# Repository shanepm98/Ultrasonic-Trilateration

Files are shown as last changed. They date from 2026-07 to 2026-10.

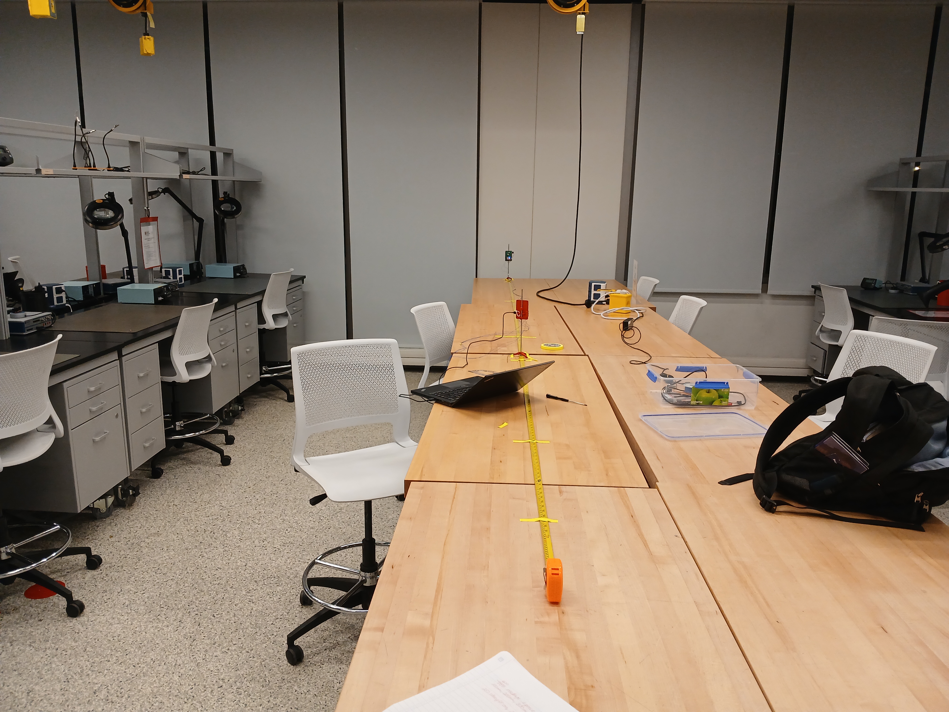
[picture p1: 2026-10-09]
pics/Testing/test_setup.jpg

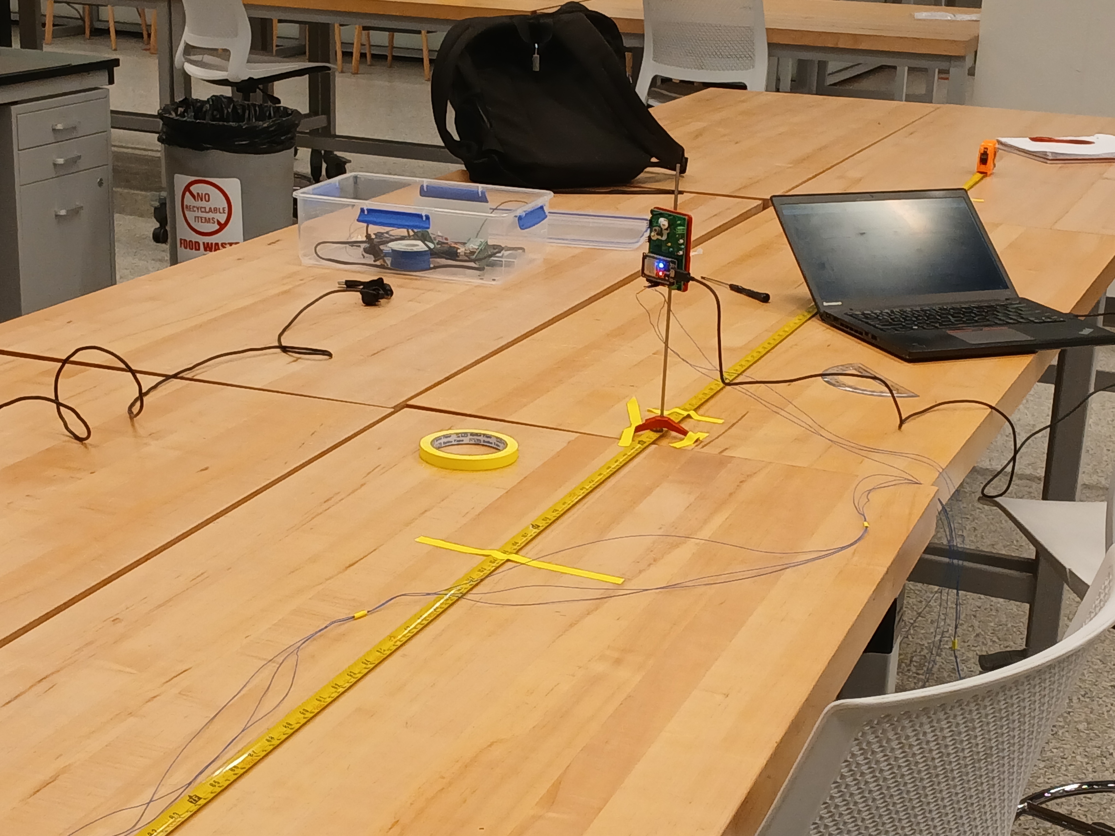
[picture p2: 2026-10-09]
pics/Testing/receiver.jpg

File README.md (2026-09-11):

# Ultrasonic Trilateration
The goal of this project is to develop a close-quarters indoor positioning system using ultrasonic trilateration.

This is essentially a small-scale, localized analog of GPS, but using ultrasonic soundwaves instead of radio, and the object being tracked emits the signal rather than the beacons.

## Repo overview
- `docs/` contains all documentation for the project. Theory of operation, results of testing, assembly instructions, etc. `docs/datasheets/` holds component datasheets.
- `src/` contains all source code and firmware:
  - `src/components/` - reusable ESP-IDF components: `invn-soniclib` (vendored SonicLib), `soniclib_esp32_bsp` (the ESP32 board support package for SonicLib), `icu_post` (power-on self-test).
  - `src/apps/` - firmware applications that consume those components (e.g. `echo_mode_hardware_test`).
- `CAD/` contains all electronics schematics, PCB files, and any relevant 3D CAD files
- `pics/` contains pictures of the project

See `CLAUDE.md` for a fuller layout and build instructions.

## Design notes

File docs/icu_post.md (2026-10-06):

# icu_post — ICU-20201 power-on self-test

Component: `src/components/icu_post/` (`icu_post.{c,h}`). See its `README.md` for the short
API summary and how to wire it into a new app's `CMakeLists.txt`; this page is the fuller
explanation of what each stage does, how to read a failure, and how the module fits the rest of
the codebase.

## Purpose

A fast, reusable "is the sensor alive and talking?" check that firmware can run at boot before
doing anything else. It is deliberately **SonicLib-level only** — no direct esp-idf or ESP32 BSP
calls beyond `esp_log` — so it stays valid if the board support package or wiring changes. All
hardware access goes through the `chbsp_*` callbacks that whichever BSP the app links against
already implements (currently `soniclib_esp32_bsp`, see `docs/board_support_package.md`). Any app
in `src/apps/` can call `post_run()` without depending on ESP32-specific headers.

## Usage contract

`post_run()` operates on an already-initialised sensor. The caller is responsible for, in order:

1. `ch_group_init(&grp, CHIRP_MAX_NUM_SENSORS, CHIRP_NUM_BUSES, CHIRP_RTC_CAL_PULSE_MS)`
2. `ch_init(&dev, &grp, 0, icu_gpt_init)`
3. The BSP's hardware init (e.g. `chbsp_esp32_init(&grp)`) — sets up GPIO/SPI/ISR so the sensor
   is reachable. This step is **not** `post_run()`'s job; see `docs/board_support_package.md` for
   why it must happen between `ch_init()` and any call that reaches the sensor.

```c
post_config_t cfg;
post_config_default(&cfg);
post_result_t res;
bool ok = post_run(&grp, &dev, &cfg, &res);
post_report(&res);
```

`cfg` and `res` may both be `NULL` if only the boolean pass/fail matters. `post_report()` is
callable independently any time after `post_run()`, to re-dump the last result from application
code.

## Stages

Stages run in order; `cfg.stop_on_fail` (default `true`) skips remaining stages after the first
hard failure so a bad SPI link doesn't cascade into confusing downstream errors.

### 1. SPI link — `chdrv_prog_ping()`

Resets the sensor through its `SYS_CTRL` register (asserts debug mode + reset, then releases
reset) and reads back the `CPU_ID_HI` debug register over SPI, checking it equals
`SHASTA_CPU_ID_HI_VALUE` (`0x2041`). Before calling `chdrv_prog_ping()` itself, `icu_post` does
its own raw read of the same register and logs the value — this raw value is what pins down the
failure mode when the ping fails:

| Raw `CPU_ID_HI` | Meaning |
|---|---|
| `0x0000` | MISO reads all-0 — sensor unpowered (check the 1.8V VDD rail), no SCLK, or MISO not wired |
| `0xFFFF` | MISO reads all-1 — MISO floating / not driven; check the MISO line, CS (GPIO5), FFC seating |
| any other wrong value | SPI mode wrong (must be **mode 3**, CPOL=1 CPHA=1), bit order wrong, clock too fast, or a level-shifter problem |
| a BSP SPI transfer error | The `chbsp_spi_*` callback layer itself failed — an SPI bus problem in the BSP, not the sensor |

A pass here proves wiring, chip-select, SPI mode, bit order and framing are all correct end to
end — it is the "can the ESP32 (or whichever host) talk to the module over SPI" headline check,
also exposed as `post_result_t.spi_link_ok`.

### 2. Program + start — `ch_group_start()` + `ch_sensor_is_connected()`

Runs SonicLib's full discovery: firmware download to the sensor, frequency lock, and RTC
calibration, then confirms `ch_sensor_is_connected()`. This is the expensive stage — it is
skipped entirely if `cfg.run_group_start` is `false`, leaving stage 1 as a fast SPI-only smoke
test (useful for a quick wiring check without the cost of a full firmware download).

### 3. Sensor identity — parameter read-back and sanity check

Reads back part number, sensor ID (lot + serial from OTP, or `"NOTPROG"` if OTP is blank),
firmware version string, operating frequency, and RTC calibration result, then checks:

- part number matches `cfg.expected_part_number` (default `ICU20201_PART_NUMBER` = 20201; set to
  `0` to disable the check)
- operating frequency is within 65–100 kHz. The ICU-20201's datasheet (DS-000478) specifies
  70–95 kHz, nominal 85 kHz, across process/temperature; the window adds a little margin. A reading
  outside it fails the stage, because SonicLib derives every sample count and range conversion
  from this frequency. Two readings get their own messages:
  - `0` — the frequency-lock step didn't work.
  - `1` (`PMUT_FREQUENCY_ERROR_CODE`) — SonicLib's PMUT clock count during `ch_group_start()` came
    back ~0, so it substituted 1 Hz. Seen on hardware 2026-10-05 (receiver board); left
    unchecked it produced a 1-sample measurement and a 61 m "max range".
- RTC calibration result is non-zero

## Result structures

`post_result_t` (see `include/icu_post.h` for the authoritative field list):

- `all_pass` — every *attempted* stage passed (a skipped stage doesn't count against this)
- `spi_link_ok` — headline stage-1 result
- `stage[POST_STAGE_COUNT]` — per-stage `post_stage_result_t { run, pass, code, detail }`
- `part_number`, `sensor_id`, `fw_version`, `op_frequency_hz`, `rtc_cal_result` — filled in once
  stage 3 runs

`post_config_t`:

- `run_group_start` (default `true`) — run stages 2–3; `false` restricts POST to the SPI-link
  smoke test
- `stop_on_fail` (default `true`) — abort remaining stages after the first hard failure
- `expected_part_number` (default `ICU20201_PART_NUMBER`) — `0` disables the stage-3 part-number
  check

## Why SonicLib-level only

The module intentionally avoids any esp-idf or ESP32-specific header beyond `esp_log`. Everything
it does — `chdrv_prog_ping()`, `ch_group_start()`, the `ch_get_*()` read-backs — goes through
SonicLib's own API, which in turn reaches hardware only via the `chbsp_*` callback interface a BSP
implements. That means `icu_post` needs no changes if the BSP is swapped (a different MCU, a
different wiring layout) or if a second/third sensor is added — it only assumes one already-`ch_init()`'d
sensor `ch_dev_t` was handed to it, which is the same assumption every SonicLib application makes.

The one exception is `#include "esp_log.h"` (`ESP_LOGI`/`ESP_LOGW`/`ESP_LOGE`) for console output;
this is esp-idf-specific but is the same logging facility every app in this repo already uses, so
it was judged not worth abstracting away.

The component also carries a compile-time guard (`#if !defined(INCLUDE_SHASTA_SUPPORT) ||
defined(INCLUDE_WHITNEY_SUPPORT)`) that fails the build if SonicLib wasn't configured for the
Shasta/SPI path the ICU-20201 needs — see "SPI vs I2C" in `docs/hardware_bringup.md` for why that
distinction matters.

## Example / reference usage

`src/apps/echo_mode_hardware_test/main/post_main.c` is the working reference: it runs
`post_run()` in a retry loop (every 5 s on failure) so the FFC/wiring can be re-seated and watched
for recovery, then hands off to the rangefinding loop once POST passes. See
`docs/hardware_bringup.md` for the bring-up narrative and current hardware status.

## Including in a new app

See the "Adding this component to a new app" section of `src/components/icu_post/README.md` for
the `CMakeLists.txt` / `REQUIRES` wiring.

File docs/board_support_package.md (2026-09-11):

# ESP32 SonicLib Board Support Package

Location: `src/components/soniclib_esp32_bsp` (an ESP-IDF component).

This is a board support package (BSP) that lets [TDK/InvenSense SonicLib
v4](https://github.com/tdk-invn-oss/ultrasonic.soniclib) drive a single ICU-20201 ultrasonic
sensor from an ESP32 (DevkitV1) running ESP-IDF's FreeRTOS. It implements the `chbsp_*` callback
interface SonicLib requires (declared in `invn/soniclib/chirp_bsp.h`) but is not itself an
application - it has no measurement logic and no `app_main()`. It is consumed as a component by
the apps under `src/apps/`.

## Hardware target

Single ICU-20201 sensor wired to the ESP32 over SPI, matching
`CAD/Rangefinder_test_schematic_v3`:

| Signal | ESP32 GPIO | ICU-20201 pin | Role |
|---|---|---|---|
| MOSI | GPIO23 | 3 | SPI |
| MISO | GPIO19 | 4 | SPI |
| SCLK | GPIO18 | 2 | SPI |
| CS | GPIO5  | 5 | SPI, manual (software) chip-select |
| INT1 | GPIO2  | 6 | Hardware trigger (output, external 2.2k pull-up to 3.3V) |
| INT2 | GPIO4  | 7 | Data-ready interrupt (input, external 2.2k pull-up to 3.3V) |

No I2C, RESET_N, or PROG lines are used - ICU/Shasta-generation sensors don't have them. Pin
numbers and SPI parameters (host, clock speed, DMA scratch buffer size) live in
`esp32_bsp_internal.h` if the wiring ever changes.

SPI is **mode 3** (CPOL=1, CPHA=1) - required by the ICU-20201, DS-000478 Table 1 (pin 2 SCLK)
and AN-000357 Table 1 (pin 10 SCLK). Set in `chbsp_esp32_init.c` (`devcfg.mode = 3`). Clock is a
conservative 1 MHz (`BSP_SPI_CLOCK_HZ`); datasheet max is 13 MHz. INT1/INT2 are open-drain on the
sensor, held high by the external 2.2k pull-ups; fine for a single board, but relevant if the INT1
trigger line is ever wired between two boards for pitch-catch (see `CAD/Rangefinder_test_schematic_v3`).

Wiring above matches `CAD/Rangefinder_test_schematic_v3` (SPI unchanged from the earlier revision
the BSP was first written against).

## File layout

The BSP component is `src/components/soniclib_esp32_bsp/`:

- `include/chbsp_esp32_init.h` - the one public header: `chbsp_esp32_init()`. See "Usage" below.
- `esp32_bsp_internal.h` - pin assignments and hardware handles shared between the two `.c`
  files. Private (`PRIV_INCLUDE_DIRS`), not part of the public interface. Also carries the
  compile-time `#error` guard requiring `INCLUDE_SHASTA_SUPPORT`.
- `chbsp_esp32_init.c` - one-time GPIO/SPI/ISR/event-group/task setup.
- `esp32_bsp.c` - the `chbsp_*` implementations, the GPIO ISR handler for INT2 (data-ready), and
  `bsp_int_task` (see "Interrupt handling" below). Includes the vendored
  `<invn/soniclib/chirp_bsp.h>` directly (no local copy).

The vendored SonicLib lives in a separate component, `src/components/invn-soniclib/` (ICU/Shasta
support + GPT rangefinding firmware only). Its `CMakeLists.txt` sets the board configuration
(`CHIRP_MAX_NUM_SENSORS`, `CHIRP_NUM_BUSES`, `CHIRP_SENSOR_INT_PIN`, `CHIRP_SENSOR_TRIG_PIN`,
`MAX_PROG_XFER_SIZE`, `INCLUDE_SHASTA_SUPPORT`, `CH_LOG_MODULE_LEVEL`) via `PUBLIC` compile
definitions rather than a `chirp_board_config.h` file, so there's no circular dependency between
the library and the BSP.

## Usage

An application that wants to use this BSP must call `chbsp_esp32_init()` **after**
`ch_group_init()`/`ch_init()` (so the `ch_group_t`/`ch_dev_t` exist) and **before**
`ch_group_start()` (so the SPI/GPIO/interrupt hardware is ready when SonicLib starts probing the
sensor):

```c
#include <invn/soniclib/soniclib.h>
#include <invn/soniclib/sensor_fw/icu_gpt/icu_gpt.h>
#include "chbsp_esp32_init.h"

static ch_group_t grp;
static ch_dev_t dev;

void app_main(void) {
    ch_group_init(&grp, CHIRP_MAX_NUM_SENSORS, CHIRP_NUM_BUSES, CHIRP_RTC_CAL_PULSE_MS);
    ch_init(&dev, &grp, 0, icu_gpt_init);

    chbsp_esp32_init(&grp);   /* sets up GPIO/SPI/ISR/event group - must run before ch_group_start() */

    ch_group_start(&grp);
    /* ch_sensor_is_connected(&dev) should now be true; proceed to ch_set_config()/ch_set_mode()/
       ch_group_trigger() etc. as normal SonicLib application code. */
}
```

To use the BSP from another app, point that app's `EXTRA_COMPONENT_DIRS` at `src/components/`
(see `src/apps/echo_mode_hardware_test/CMakeLists.txt`) and add `soniclib_esp32_bsp` to your component's
`REQUIRES`. It brings `invn-soniclib` in transitively.

## What's implemented vs. not

Implemented for real: INT2 (data-ready interrupt) direction/level/enable control, INT1 (hardware
trigger) direction/level control, manual SPI chip-select plus blocking SPI read/write (routed
through a DMA-capable scratch buffer), microsecond/millisecond delay, millisecond timestamp, and
the event-wait/notify primitives SonicLib uses internally during `ch_group_start()` (backed by a
FreeRTOS event group).

Deliberately not implemented (the sensor/board don't need them, or SonicLib's ICU/Shasta code
path never calls them - see `invn/soniclib/chirp_bsp.h` for which functions are
Whitney/CH101/CH201-only):
I2C (any of it), sensor RESET_N/PROG control, debug indicator pins (none wired on this board),
and non-blocking SPI I/Q readout (`chbsp_spi_mem_read_nb` - can be added later if needed). These
fall back to the harmless no-op weak stubs in SonicLib's own `chbsp_dummy.c`.

## Interrupt handling

SonicLib's `ch_interrupt()` (called on each data-ready) runs `chdrv_int_callback_deferred()`,
which does blocking SPI reads (interrupt-source register, measurement metadata) and calls the
application's data-ready callback. That cannot run in ISR context - `spi_device_transmit()` would
deadlock (the earlier bring-up hit an "Interrupt wdt timeout ... running in ISR context" panic).

So the BSP splits it: `bsp_int2_isr_handler` (the GPIO ISR) does nothing but
`vTaskNotifyGiveFromISR(bsp_int_task_handle)`. A dedicated high-priority task, `bsp_int_task`,
takes that notification and calls `ch_interrupt(bsp_grp_ptr, 0)` at task level, then re-arms the
GPIO interrupt (`chdrv_int_callback()` disables it while it toggles the INT pin). This path
serves both `ch_group_start()` and normal measurements, so `USE_DEFERRED_INTERRUPT_PROCESSING` is
**not** defined. `chbsp_event_notify()` is written ISR-safe anyway (`xPortInIsrContext()` check).

An application registers its data-ready callback with `ch_io_int_callback_set()`; SonicLib invokes
it from `bsp_int_task` context, so it may call `ch_get_range()` etc. directly (see
`src/apps/echo_mode_hardware_test/main/rangefinder_loop.c`).

One deliberate deviation from the "obvious" FreeRTOS approach: `chbsp_delay_ms()` busy-waits
(`esp_rom_delay_us()`) rather than calling `vTaskDelay()`. `CONFIG_FREERTOS_HZ=100` gives only
10ms tick resolution, which is too coarse for the RTC calibration pulse this function times
during `ch_group_start()` - `chirp_bsp.h` notes that pulse's accuracy directly affects range
accuracy. This only blocks the calling task for tens to hundreds of ms during one-time startup
calibration, not during normal measurement.

## Building

The BSP is a component, not a standalone project - it is built as part of whichever app pulls it
in. `cd src/apps/echo_mode_hardware_test && ./build.sh` exercises it.

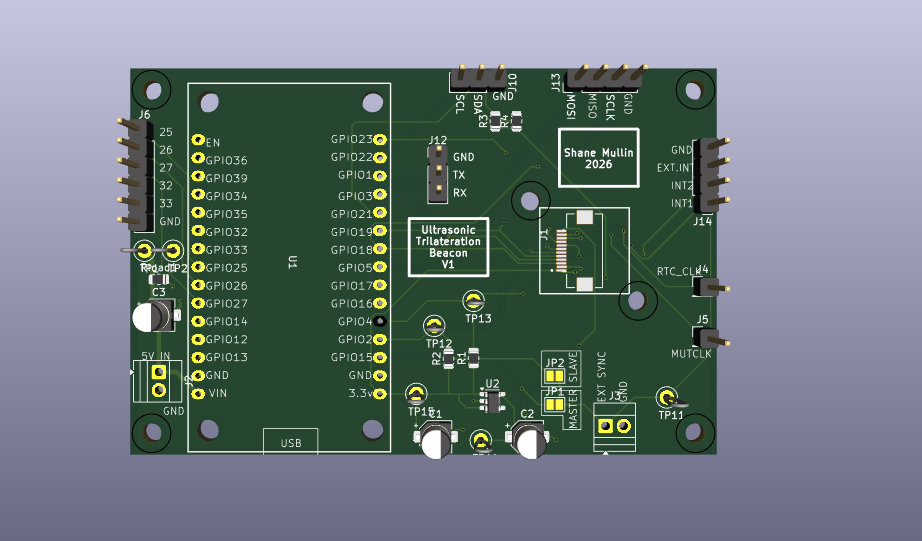
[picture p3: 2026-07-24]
pics/PCB.png

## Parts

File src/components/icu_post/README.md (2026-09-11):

# icu_post

Reusable power-on self-test (POST) for a single ICU-20201 ultrasonic sensor reached over SPI via
TDK/InvenSense SonicLib. SonicLib-level only — no direct esp-idf/BSP calls beyond `esp_log` — so
any app can call it at boot regardless of which board support package or wiring is in use. See
`docs/icu_post.md` for the full explanation of each stage and how to interpret a failure.

## Stages

| # | Stage | Call | A pass proves |
|---|---|---|---|
| 1 | SPI link | `chdrv_prog_ping()` (plus a raw `CPU_ID_HI` debug-register read for diagnostics) | Wiring, chip-select, SPI mode, bit order and framing are all correct end to end |
| 2 | Program + start | `ch_group_start()` then `ch_sensor_is_connected()` | Firmware downloaded, frequency locked, RTC calibrated |
| 3 | Sensor identity | reads part number / serial / fw version / operating frequency / RTC cal result | The programmed sensor reports sane values (part `20201`, f_op ~85 kHz) |

## API

```c
#include "icu_post.h"

post_config_t cfg;
post_config_default(&cfg);      // full test, stop-on-fail, expect ICU20201_PART_NUMBER
// cfg.run_group_start = false;    // SPI-link-only smoke test
// cfg.stop_on_fail    = false;    // run every stage regardless of earlier failures
// cfg.expected_part_number = 0;   // disable the part-number check

post_result_t res;
bool ok = post_run(&grp, &dev, &cfg, &res);   // grp/dev already ch_group_init()/ch_init()'d
post_report(&res);                            // dump the result table (ESP_LOG, tag "POST")
```

`post_run()` does **not** call `chbsp_esp32_init()` — the caller must already have run
`ch_group_init()`, `ch_init()`, and the BSP's hardware init before calling it. `cfg` and `out` may
both be `NULL` if only the `bool` return value matters. See `include/icu_post.h` for the full
`post_result_t` / `post_stage_result_t` field docs.

## Adding this component to a new app

1. Point the app's `CMakeLists.txt` at the shared components directory:
   ```cmake
   set(EXTRA_COMPONENT_DIRS "${CMAKE_CURRENT_LIST_DIR}/../../components")
   ```
2. Add `icu_post` to the consuming source file's component `REQUIRES` (it pulls in
   `invn-soniclib` transitively):
   ```cmake
   idf_component_register(SRCS "main.c"
                           REQUIRES soniclib_esp32_bsp icu_post invn-soniclib log)
   ```
3. Call it after `ch_group_init()` / `ch_init()` / the BSP's init, before doing anything else with
   the sensor:
   ```c
   ch_group_init(&grp, CHIRP_MAX_NUM_SENSORS, CHIRP_NUM_BUSES, CHIRP_RTC_CAL_PULSE_MS);
   ch_init(&dev, &grp, 0, icu_gpt_init);
   chbsp_esp32_init(&grp);

   post_config_t cfg;
   post_config_default(&cfg);
   post_result_t res;
   bool ok = post_run(&grp, &dev, &cfg, &res);
   post_report(&res);
   ```

See `src/apps/echo_mode_hardware_test/main/post_main.c` for a working example (retries on
failure) and `docs/icu_post.md` for the full stage-by-stage reference.

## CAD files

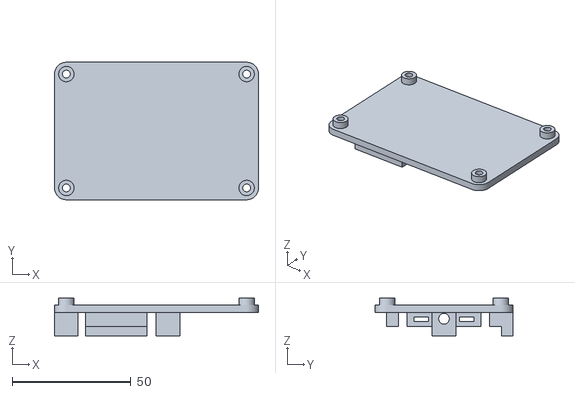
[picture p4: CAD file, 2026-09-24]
CAD/3D_Print_Files/BoardMountV1.stl
86.0 x 58.0 x 16.0

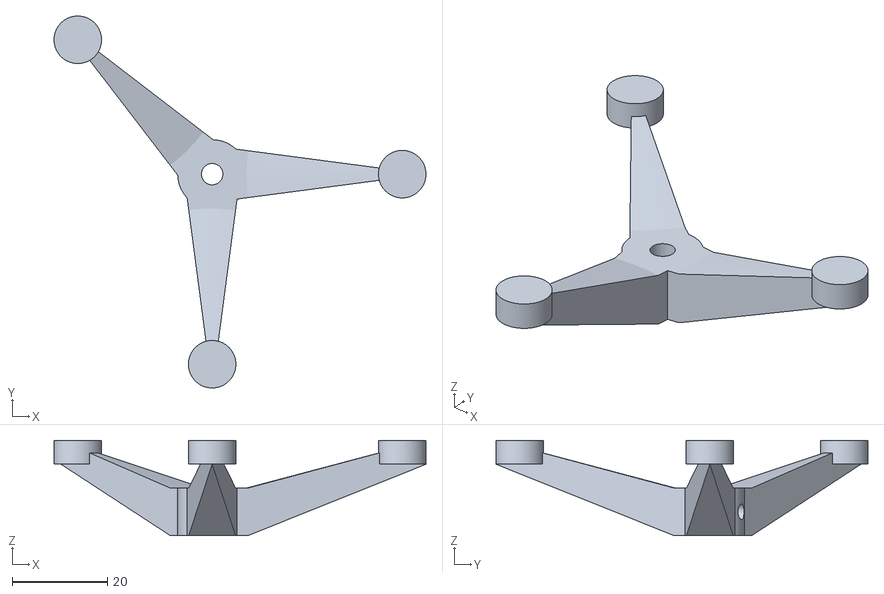
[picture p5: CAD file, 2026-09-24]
CAD/3D_Print_Files/FeetV1.stl
78.3 x 78.3 x 20.0

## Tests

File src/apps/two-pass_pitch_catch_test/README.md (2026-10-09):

# Two-Pass Pitch-Catch Mode for Finer Resolution
The idea here is to build on the existing pitch-catch application to experiment with a method for taking distance measurements at highest-ODR at 5 meter distance.
5 meter readings are normally unobtainable at max ODR, as the 340 sample window runs out slightly after 2.5 meters. But because higher ODR means higher precision,
it is desirable to try and work around this problem.

In this app, I am testing the approach of refining measurements using two chirps. The first chirp will be sampled at a lower ODR, such as f_op/4. This first
chirp will be used to get an approximate position of the sensor, that does not have to be accurate beyond a few centimeters. 
Once the approximate distance from the sender is known, the receiver will dynamically construct a new sensor configuration that samples at the maximum ODR,
F_op/2. If the target is beyond 2.5m, it will delay the receive segment with count cycles to shift the 2.5m window within the 5m range. The sender will
emit a second chirp, this time sampled at the max ODR after an appropriate delay, in order to be able to reach the entire 5m range window.

For simplicity, We only need 3 possible configurations at max ODR to be able to sample any 2.5m window in the 5m range at max ODR. Let d be the distance
from sender as approximated using the first chirp. Then our 3 configurations are:
(1) 0m <= d <= 2m: no padding needed, simply record at full ODR
(2) 2m <  d  < 3m: Pad with 1.25m worth of count cycles, then record at full ODR
(3) 3m <= d <= 5m: Pad with 2.5m worth of count cycles, then record at full ODR

It may also be necessary to account for the count cycles, if the sensor does not do this already. This will need to be determined experimentally.

## Implementation (`receiver_readout/`)
The sender is unchanged from `pitch_catch_mode_hardware_test`. It sends the same chirp every time
the receiver pulls the shared INT1 line. Only `receiver_readout/` implements the two-pass flow, as a
data-collection tool. It prints the coarse pass's distance and the fine pass's raw I/Q, so the fine
pass can be tuned offline.

The ICU sensor holds two measurement definitions, and the receiver uses one per pass:

| Slot | Pass | ODR | Queue |
|---|---|---|---|
| meas 0 | coarse | `PC_ODR` (f_op/4) | count (TX match) -> rx, ~5 m; `sc_rx_thresholds` |
| meas 1 | fine | f_op/2 | count (TX match + pad) -> rx, ~2.5 m |

The coarse pass detects with the bench-calibrated `sc_rx_thresholds` from the `sensor_calibration`
component, with its ringdown cancel tied to `SC_RX_THRESHOLDS_RINGDOWN_SAMPLES`. That table was
fitted at the coarse pass's ODR and TX burst.

For each reading the receiver:
1. Triggers the coarse pass. If it finds no target, no fine pass is run.
2. Picks the band from the coarse range (the table above). It then lengthens the fine slot's count
   segment by the pad, and sets the fine slot's thresholds to a gate around the expected arrival.
3. Makes the fine slot active (`ch_meas_standby(dev, 0)`) and waits `TP_PASS_GAP_MS`.
4. Triggers the fine pass, then switches back to the coarse slot.
5. Prints both blocks. Only the fine pass's I/Q is read from the sensor. Nothing is printed until
   both passes are done, so serial output doesn't stretch the time between the chirps.

**Count-cycle compensation (open question above).** SonicLib already handles this in software. For
an RX-only measurement, it counts every count segment before the receive segment as pre-RX time
(`ch_common_meas_update_counts()`). `icu_gpt` adds that back into the time of flight
(`get_tof_offset_lsb()`). So the fine pass's `range_mm` should already be the absolute distance.
This is **not yet confirmed on hardware**. If fine `range_mm` comes out about `pad_mm` short of the
coarse value, the compensation isn't happening.

**Fine-pass detection is a placeholder.** No captures exist at f_op/2 yet. The gate is
`TP_GATE_LEVEL` within ±`TP_GATE_HALF_MM` of the coarse distance, and unreachable everywhere else.
The level is a guess, so treat the fine pass's `target`/`range_mm` as provisional until it has been
tuned from the I/Q captured here. All `TP_*` values are at the top of `readout_loop.c`.

## Usage
Flash `sender/` and `receiver_readout/` (`./build.sh flash monitor` in each). The startup log
prints both slots' ODR as read back from the sensor; check that meas 0 is 5 and meas 1 is 6. The
console prompts for a batch the same way as `pitch_catch_mode_hardware_test` (see its README,
"Raw data readout"). Each reading prints two blocks, coarse then fine. Each block has an extra
`pass=` line after `actual_mm=`:

```
BEGIN
title=<batch title>
actual_mm=<actual distance>
pass=coarse odr=5
meas=<n> num_samples=<N> target=<0|1> range_mm=<mm|NA> amp=<u>
END
BEGIN
title=<batch title>
actual_mm=<actual distance>
pass=fine odr=6 band=<1|2|3> pad_mm=<0|1250|2500> coarse_mm=<mm>
meas=<n> num_samples=<N> target=<0|1> range_mm=<mm|NA> amp=<u>
IQ,...
END
```

`range_mm` is the sensor's range plus `TRANSMITTER_OFFSET` + `RECEIVER_OFFSET` (from
`sensor_offsets.h` in `sensor_calibration`, currently 23.25 mm each). Those offsets run from each
transducer to the base of its unit, where `actual_mm` is measured from. `coarse_mm` on the fine line
is the coarse pass's *uncorrected* range, because it is what the band and gate are computed from,
in the sensor's own time base.

Fine-pass error reasons, besides the usual `sender_not_ready` / `no_response` /
`iq_read_failed_<rc>`:
- `no_coarse_target`: the coarse pass found no target.
- `coarse_failed`: the coarse pass itself errored.
- `wrong_slot`: the data came from the other measurement slot.
- `fine_config_failed`: the pad or gate couldn't be written.

Host side:
The coarse block has only the summary line (the sensor's distance), with no `IQ` rows.

- `host/extract_measurements.py` writes `<title>_<n>_fine.csv` (coarse blocks have no I/Q, so they
  get a manifest row but no CSV). It adds
  `pass`, `band`, `pad_mm` and `coarse_mm` columns to `manifest.csv`, and takes `odr` from each block.
- `host/plot_readout.py <fine csv> --odr 6 --pad-mm <pad_mm> --op-freq <Hz>` plots a fine pass on
  an absolute distance axis.

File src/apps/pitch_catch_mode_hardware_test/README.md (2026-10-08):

# Pitch-catch hardware bring-up

Two independent ESP-IDF apps, each flashed to its own ESP32 + ICU-20201 board, doing **direct
pitch-catch** ranging: the tracked object emits (`sender/`), a fixed beacon listens
(`receiver/`) - see the top-level project guide. Each consumes the shared components in
`../../components/`: `soniclib_esp32_bsp` (the BSP), `invn-soniclib` (vendored SonicLib), and
`icu_post` (the self-test), the same way `echo_mode_hardware_test` does, plus
`sensor_calibration` (the shared sensor config). `include/` holds a header shared by both apps
(see below).

- `sender/` - sensor configured `CH_MODE_TRIGGERED_TX_RX`. Configures once, then idles.
- `receiver/` - sensor configured `CH_MODE_TRIGGERED_RX_ONLY`. Owns the periodic trigger loop.

`sender/` and `receiver/` build and flash completely independently - they don't depend on each
other's directory, only on `../../components/` and `../include/`.

## Trigger-sync architecture

Per `../../components/soniclib_esp32_bsp`'s doc and `CAD/Rangefinder_test_schematic_v3`, the two
boards' sensor INT1 (trigger) pins are physically wired together, open-drain with a shared
pull-up.

**The receiver owns the periodic trigger loop, not the sender** - an inversion of SonicLib's
"typical" example in AN-000175, where the TX/RX node usually drives the periodic timer. Here, the
receiver (`receiver_loop.c`) calls `ch_group_trigger()` on a fixed cadence, which pulses its own
GPIO2/INT1 line; because that line is shared with the sender's board, the same edge simultaneously
fires the sender's sensor. The receiver is the fixed beacon, so it knows its own trigger instant
exactly, with zero communication latency - that matters for computing time-of-flight.

The sender's firmware (`sender_loop.c`) never calls `ch_trigger()`/`ch_group_trigger()` - it only
configures its sensor for `CH_MODE_TRIGGERED_TX_RX` and reacts passively to externally-driven
trigger edges. This "passive" contract is enforced purely at the app level (never calling the
trigger functions), not by the GPIO becoming an input: `CHIRP_SENSOR_TRIG_PIN` (1) and
`CHIRP_SENSOR_INT_PIN` (2) differ on this board, so SonicLib's driver never reverts the TRIG pin
to an input after use - GPIO2 is configured push-pull output at boot regardless of whether the app
ever triggers. **Bench-check item (not a firmware fix)**: confirm the shared INT1 net tolerates
this - i.e. that only one side (the receiver) ever actually drives it low.

## Sender-ready handshake

The sender's sensor INT2 (data-ready, GPIO4 locally) is additionally wired to the receiver's
**GPIO33**, over a second physical link separate from the receiver's own local sensor INT2. The
receiver polls this pin (`gpio_get_level()`, plain ESP-IDF `driver/gpio.h`, not the `chbsp_*` BSP
API - that's scoped to a board's own local sensor) immediately before each trigger, and skips
(logging a warning) if the sender still shows busy, rather than firing on a fixed timer regardless
of sender state.

The sender's own application never touches its INT2 data (no `ch_io_int_callback_set()` call) -
but the BSP still services that interrupt transparently at the driver level (`bsp_int_task` ->
`ch_interrupt()` runs on every INT2 edge regardless of whether an app callback is registered),
which is exactly the low/high transition the receiver's GPIO33 tap observes. So the sender needs
no code to support this handshake - it falls out of the BSP's existing interrupt servicing.

## Direct pitch-catch range

The receiver's data-ready callback reads `ch_get_range(dev, CH_RANGE_DIRECT)` - the direct
pitch-catch range, since the sender and receiver are separate physical objects (not a reflected/
co-located setup). This is the only measurement the system reports; the sender produces no local
data (see above).

## Shared constants: `sensor_calibration.h` and `include/pitch_catch_common.h`

Cross-board constants - values where the sender's and receiver's independent calculations must
numerically agree for the protocol to work - live in two headers instead of being hand-duplicated
as matching `#define`s in two independent builds.

`sensor_calibration.h`, in the `src/components/sensor_calibration/` component, holds the measurement
config that every app (this one and any new one) uses. Apps get it by listing
`sensor_calibration` in `main/CMakeLists.txt`'s `REQUIRES`:

- `PC_TX_PULSE_US` / `PC_TX_PULSE_WIDTH` / `PC_TX_PHASE` - the sender's TX burst; the receiver's
  count segment must be sized from `PC_TX_PULSE_US` too (AN-000175: the count segment cycle count
  should match the other sensor's transmit cycle count).
- `PC_ODR`, `PC_MAX_RANGE_MM` - so both sensors interpret sample timing and range the same way.

`include/pitch_catch_common.h` is local to this app (`INCLUDE_DIRS "." "../../include"`). It
includes `sensor_calibration.h` and adds the values specific to this test setup:

- `PC_TRIGGER_INTERVAL_MS`, `PC_RESPONSE_TIMEOUT_MS` - the receiver's trigger cadence.
- `PC_SENDER_READY_GPIO` - the receiver's GPIO33 pin assignment for the handshake above.

Per-sensor bench-tunable calibration (RX gain/attenuation, detection thresholds, ringdown/
static-filter samples) is **not** here - those legitimately differ per physical sensor unit and
stay local to each app's own `*_loop.c`.

## Known limitations / future work

- **Frequency matching** between the two independently-calibrated sensors is not implemented.
  `ch_group_set_frequency(grp, CH_OP_FREQ_USE_AVG)` only averages frequencies within one shared
  `ch_group_t` and can't be used across two separate boards/groups.
- **Receive pre-triggering** (`ch_set_rx_pretrigger()`, a 600us ringdown-settle convenience for
  close-range accuracy) is likewise scoped to one shared `ch_group_t` and isn't usable cross-board.

See `TODO.md` for the first on-hardware bring-up checklist (bench tuning, wiring continuity,
`CH_RANGE_DIRECT` validation against a measured baseline).

## Build / flash / monitor

Each app builds and flashes independently, same pattern as `echo_mode_hardware_test`:

```sh
cd sender/      # or receiver/
./build.sh                       # idf.py build, in the espressif/idf Docker image
./build.sh flash monitor         # needs that board on $PORT (default /dev/ttyUSB0)
PORT=/dev/ttyACM0 ./build.sh flash monitor
```

`build.sh` mounts the repo `src/` directory so the shared components under `../../../components/`
and the common header under `../../include/` resolve. Console output is on UART0 (USB serial) at
115200 baud; watch for the `bringup-tx`/`pitch-catch-tx` (sender) or `bringup-rx`/`pitch-catch-rx`
(receiver) log tags.

## Wiring

Per `../../components/soniclib_esp32_bsp` and `CAD/Rangefinder_test_schematic_v3`, **each board**
(sender and receiver) has the same local SPI wiring:

| Signal | ESP32 GPIO | ICU-20201 | Notes |
|---|---|---|---|
| MOSI | 23 | pin 3 | |
| MISO | 19 | pin 4 | |
| SCLK | 18 | pin 2 | SPI mode 3 (CPOL=1, CPHA=1) |
| CS | 5  | pin 5 | manual/software chip-select |
| INT1 | 2  | pin 6 | hardware trigger out (`CHIRP_SENSOR_TRIG_PIN=1`); open-drain, 2.2k pull-up |
| INT2 | 4  | pin 7 | data-ready interrupt in (`CHIRP_SENSOR_INT_PIN=2`); open-drain, 2.2k pull-up |

Plus two board-to-board links, specific to this pitch-catch pair:

| Link | Sender pin | Receiver pin | Purpose |
|---|---|---|---|
| Shared trigger | INT1 (GPIO2) | INT1 (GPIO2) | Receiver's `ch_group_trigger()` fires both sensors |
| Sender-ready | INT2 (GPIO4) | GPIO33 | Receiver checks sender's data-ready state before retriggering |

VDD = 1.8V regulated; VDDIO may be 3.3V (direct to the ESP32). Both boards need this rail
independently.

## Raw data readout

`receiver_readout/` is a modified version of `receiver/` - same sensor configuration (measurement
queue, `icu_gpt` algorithm/thresholds, `CH_MODE_TRIGGERED_RX_ONLY`), same sender-ready GPIO33
check - but instead of reporting the computed distance on a fixed 10 Hz cadence, it dumps the raw
I/Q trace of each measurement as plain text, for offboard signal processing (e.g. bench-tuning the
thresholds/gain against real waveforms in a separate program).

A full I/Q dump (up to `ICU_MAX_NUM_SAMPLES` samples x 4 bytes, ~1.4 KB) doesn't fit inside a
100 ms trigger interval over a typical console baud rate, so this variant collects **labelled
batches** instead of free-running. The serial console prompts for:

1. a batch title (free text, printable ASCII, up to 63 characters),
2. the actual (tape-measured) sender-receiver distance in mm (1..`PC_MAX_RANGE_MM`),
3. the number of readings (1..1000),

then waits for Enter and fires that many readings back-to-back. Typed input is echoed and
Backspace works. Before each trigger it waits up to `PC_TRIGGER_INTERVAL_MS` for the sender-ready
line (sender INT2 -> receiver GPIO33) to read high. After a batch it prompts for the next title.

Each reading prints exactly one block, so a batch of N always has N blocks:

```
BEGIN
title=<batch title>
actual_mm=<actual distance>
meas=<n> num_samples=<N> target=<0|1> range_mm=<mm|NA> amp=<u>
IQ,<sample index>,<I>,<Q>
...
END
```

`meas` counts from 1 within the batch; `range_mm`/`amp` are the sensor's own `icu_gpt` result. A
failed reading has a single `meas=<n> error=<reason>` line in place of the summary and `IQ` rows,
where reason is `sender_not_ready` (GPIO33 stayed low), `no_response` (no data-ready within
`PC_RESPONSE_TIMEOUT_MS`) or `iq_read_failed_<rc>`.

The blocks are plain `printf` lines (not `ESP_LOGx`), so a host-side script can grep for them and
ignore interleaved log output.

### Extracting a capture

Log the serial session to a file (e.g. `picocom ... --logfile capture.txt`), then:

```
./receiver_readout/host/extract_measurements.py capture.txt -o readouts/bench --op-freq 84930 --odr 4
```

This writes one `idx,i,q` CSV per reading, named `<title>_<meas>.csv`, plus `manifest.csv` with one
row per block: `title, actual_mm, meas, num_samples, target, range_mm, amp, error, odr, op_freq_hz,
file`. The operating frequency and ODR set the sample spacing, so they affect every distance derived
from the I/Q data. Take them from the receiver's startup log (`op freq ... Hz` and `sensor ODR: N`).
`--odr` defaults to 4 (`PC_ODR`). `--op-freq` has no default; without it the column is blank. Older
`IQ_BEGIN`/`IQ_END` captures (e.g. `readouts/session.txt`) are still accepted; pass `--prefix` to
name their files.

### Plotting a recording

`receiver_readout/host/plot_readout.py` (standard library only, no venv needed) renders a CSV of
`idx,i,q` rows - e.g. the `IQ,` lines of one measurement, grepped out of a captured console log
and given a header row - as an interactive HTML waveform plot (amplitude envelope + raw I/Q,
synced hover, ringdown/threshold context pulled from `readout_loop.c`'s current config):

```
./host/plot_readout.py recording.csv --open
./host/plot_readout.py recording.csv --target 0 --range-mm 193.2   # from the block's meas= line
```

See `plot_readout.py --help` for the threshold/ringdown override flags (only needed if
`readout_loop.c`'s `rx_thresholds`/`RX_RINGDOWN_CANCEL_SAMPLES` have since been re-tuned).

### Calibrating the detection thresholds

`receiver_readout/host/calibrate_thresholds.py` fits an 8-segment threshold table to an extracted
capture directory (default `readouts/parsed`), replays it against every reading, and writes it to
`src/components/sensor_calibration/rx_thresholds.c` (`--dry-run` to only report). See
`docs/threshold_calibration.md`.

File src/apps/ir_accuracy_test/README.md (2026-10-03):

# Pitch-Catch mode test using infrared trigger synchronization
Previous hardware tests have verified that two boards can operate in pitch-catch mode using a hardwired connection between sensor trigger pins.

In this iteration, the hardwired sensor trigger line is made wireless using infrared. Each board has both an IR LED and 38KHz IR demodulator, where the demodulator output triggers the ultrasonic sensor.

To begin a measurement, the receiver board pulses it's own IR LED with 5 milliseconds of a 38KHz 50% duty-cycle PWM signal to GPIO25. This IR signal triggers both its own IR demodulator as well as the IR demodulator on the sender board.
On both boards, the output of the demodulator triggers the ultrasonic sensor. This method is used to keep symmetric latency (and thus more simultaneous triggering) on both sender and receiver.

## Functional description
- Like in the `pitch_catch_mode_hardware_test`, the receiver controls the measurement loop
- The sender is triggered by the receiver
- 38KHz IR drive signal generated using the ESP32's RMT peripheral (hardware carrier modulation; the
  whole pre-burst/gap/trigger waveform is timed in hardware to 1 us)

## Receiver console menu

After POST the receiver shows a menu with the current IR timing. Press `1`/`2`/`3` to pick a mode;
in modes 2 and 3, `m` returns to the menu.

**1) IR timing tuner**: sets the IR trigger waveform used by every later trigger in modes 2 and 3.
1) `Enable pre-burst? (y/n)`. On `y`: `pre-burst ON time (us)`, then `pre-burst OFF time (us)`.
   Type a number and press Enter.
2) `trigger burst time (us)`, asked whether or not the pre-burst is enabled.
3) Then press **Enter** to save and return to the menu, **Space** to fire a test trigger (as many
   times as you like, for the oscilloscope), or **Backspace** to start the configuration over.

The waveform is: carrier ON for `pre_on_us`, OFF for `pre_off_us` (both only if the pre-burst is
enabled), then carrier ON for `trigger_us`. Each value is 1..100000 us (`IR_MAX_SEGMENT_US`).
Typed digits are echoed, Backspace deletes a digit while typing a number, and out-of-range or
empty entries re-prompt. Each test shot also triggers both sensors, and the tuner reports whether
the receiver's sensor answered (`receiver INT2: yes/NO`). The settings live in RAM only: on reboot
they reset to pre-burst disabled, trigger 5000 us (`IR_BURST_US`).

**2) Raw I/Q readout**: Enter fires one trigger, waits for INT2 (up to 500 ms), and prints the I/Q
dump (see "Output format"). On timeout it prints a warning instead.

**3) Distance**: Enter fires one trigger and prints one line with the sensor's own computed direct
pitch-catch range: `RANGE meas=<n> target=<0|1> range_mm=<mm|NA> amp=<u>`. This mode skips the
I/Q readout, so it responds faster.

Before each trigger the receiver discards any measurement a stray IR trigger produced since the
last request (logged as `discarding an unrequested measurement`). The tuner's test shots are
consumed the same way and never show up as a later reading.

## Status

**Verified on hardware (2026-09-28):** the end-to-end test passes - Enter on the receiver fires
the IR burst, both sensors trigger via their demodulators, and the receiver dumps the I/Q trace.
The trigger edge and LED polarity are confirmed (see "Bench notes" below). The trigger skew
between the two boards has not been measured yet.

## Layout

Same shape as `../pitch_catch_mode_hardware_test/` - two independent ESP-IDF apps, one per board,
each consuming the shared components in `../../components/`:

- `sender/` - sensor configured `CH_MODE_TRIGGERED_TX_RX`. Configures once, then idles; its IR
  demodulator fires the sensor. Sensor config identical to the wired test's `sender/`.
- `receiver/` - sensor configured `CH_MODE_TRIGGERED_RX_ONLY`. Owns the console menu and the
  measurement modes (`main/readout_loop.c`), the tuner dialog (`main/ir_tuner.c`), keypress input
  (`main/console_io.c`), and the RMT IR waveform driver (`main/ir_led.c`). Sensor config is
  identical to the wired test's `receiver_readout/`.
- `include/ir_common.h` - cross-board constants: the sensor values carried over unchanged from
  `pitch_catch_common.h` (`PC_TX_*`, `PC_ODR`, `PC_MAX_RANGE_MM`) plus the IR link
  (`IR_LED_GPIO`, `IR_CARRIER_HZ`, `IR_BURST_US` (default trigger length), `IR_MAX_SEGMENT_US`,
  `IR_RESPONSE_TIMEOUT_MS`, `IR_POWER_GPIO`).
- `host/` - `extract_measurements.py` / `plot_readout.py`, same as the wired test's (see
  "Output format" below).

## INT1 / GPIO2 is high-impedance

The demodulator output drives the sensor's INT1 pin, which is also wired to ESP32 GPIO2.
`chbsp_esp32_init()` leaves GPIO2 a push-pull output held high (the BSP's normal trigger-out
role), which would fight the demodulator pulling the line low. Both apps therefore call
`chbsp_group_set_int1_dir_in()` right after POST, before configuring the sensor, leaving GPIO2 a
plain input with no pulls. Neither app ever calls `ch_trigger()`/`ch_group_trigger()` - SonicLib's
trigger routines switch the pin back to an output.

## Output format

In mode 2, each Enter keypress prints, on success:

```
IQ_BEGIN meas=<n> num_samples=<N> target=<0|1> range_mm=<mm|NA> amp=<u> pre_on_us=<us> pre_off_us=<us> trig_us=<us>
IQ,<sample index>,<I>,<Q>
...
IQ_END
```

or on timeout, a `no INT2 within 500 ms` warning. The trailing `pre_on_us`/`pre_off_us`/`trig_us`
fields record the IR waveform the capture was taken with (`0` = pre-burst disabled); the host
parser ignores them. `IQ_BEGIN`/`IQ,`/`IQ_END` (and mode 3's `RANGE`) are plain `printf` lines (not
`ESP_LOGx`), so the host scripts ignore interleaved log output and menu text:

```
./host/extract_measurements.py capture.txt --prefix 2m -o readouts/2m
./host/plot_readout.py readouts/2m/2m_1.csv --open
```

## Build / flash / monitor

```sh
cd sender/      # or receiver/
./build.sh                       # idf.py build, in the espressif/idf Docker image
PORT=/dev/ttyUSB0 ./build.sh flash monitor
```

Console is UART0 at 115200 baud; log tags are `bringup-ir-tx`/`ir-pitch-catch-tx` (sender) and
`bringup-ir-rx`/`ir-pitch-catch-rx` (receiver).

## Wiring (per board)

Local SPI/INT wiring is the same as `../pitch_catch_mode_hardware_test/README.md`. There are no
board-to-board wires. Additions:

| Signal | ESP32 GPIO | Notes |
|---|---|---|
| IR LED drive | 25 | 38 kHz RMT carrier; active-high (GPIO high = LED on, idles low/off) - confirmed on hardware. Only the receiver drives it. |
| Demodulator out | - | to sensor INT1 (the INT1 net, 2.2k pull-up) |
| INT1 | 2 | high-impedance input; not driven by firmware |
| IR module power | 26 | driven high at the very start of `app_main()` (before POST) and never changed - `ir_power_on()` in `include/ir_common.h`. Both boards. |

## Bench notes

- **Signal polarity / trigger edge (confirmed 2026-09-28)**: the IR LED idles low (off), the
  demodulator output is active-low, and the ICU's INT1 trigger is active-low. So INT1 goes low,
  and the measurement starts, as soon as the demodulator detects the start of the IR burst. The
  timing reference is therefore the demodulator's burst-*start* latency, the same on both boards.
  SonicLib's own trigger is a microsecond-scale low pulse, while the demodulator holds INT1 low
  for roughly the whole trigger burst (5 ms by default). That works on hardware, and the burst length does not affect
  trigger timing. It only needs to exceed the demodulator's minimum burst length.
- **Stray IR**: ambient IR (remotes, sunlight flicker) can make a demodulator fire and trigger a
  measurement nobody asked for. The receiver drains any such measurement before each burst and
  logs `discarding an unrequested measurement`.
- **Terminal line endings**: a terminal that sends CR+LF for Enter delivers two Enter bytes;
  `console_getc()` treats a second Enter byte within 20 ms of the first as the same keypress.

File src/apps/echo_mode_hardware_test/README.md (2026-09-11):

# Hardware bring-up

ESP-IDF app for bringing up the EV_MOD_ICU-20201 ultrasonic module wired to an ESP32 DevKitV1.
It consumes the shared components in `../../components/`: `soniclib_esp32_bsp` (the BSP),
`invn-soniclib` (vendored SonicLib), and `icu_post` (the self-test below).

## Power-on self-test — the `icu_post` component

`../../components/icu_post/` (`icu_post.{c,h}`) — a modular, reusable check that the ESP32 can
talk to the sensor over SPI. SonicLib-level only (no direct esp-idf calls beyond `esp_log`), so
any app can call `post_run()` at boot regardless of BSP/wiring changes. See
`../../components/icu_post/README.md` for the API summary and `../../../docs/icu_post.md` for the
full stage-by-stage reference.

`main/post_main.c` is the bring-up harness: it does `ch_group_init` -> `ch_init` ->
`chbsp_esp32_init` -> `post_run` -> `post_report`, retrying every 5 s on failure. Once the POST
passes it calls `rangefinder_run()` (below). It is **not** the production `app_main`.

## Rangefinding loop — `main/rangefinder_loop.{c,h}`

`rangefinder_run()` configures the sensor for **free-running mode at 5 m** full-scale range
(10 Hz) and prints each measured one-way distance to the console (`rangefinder: #N <dist> mm`, or
`no target`). The transmit/receive/threshold `#define`s at the top of `rangefinder_loop.c` are
bring-up starting points to tune on the bench. Data-ready is handled from the BSP's `bsp_int_task`
(task level), so the callback reads `ch_get_range()` directly.

## Build / flash / monitor

```sh
./build.sh                       # idf.py build, in the espressif/idf Docker image
./build.sh flash monitor         # needs the board on $PORT (default /dev/ttyUSB0)
PORT=/dev/ttyACM0 ./build.sh flash monitor
```

`build.sh` mounts the repo `src/` directory so the shared components under `../../components/`
resolve. Console output is on UART0 (USB serial) at 115200 baud; watch for the `POST` /
`bringup` log tags.

## Wiring

Per `../../components/soniclib_esp32_bsp` and `CAD/Rangefinder_test_schematic_v3`:

| Signal | ESP32 GPIO | ICU-20201 | Notes |
|---|---|---|---|
| MOSI | 23 | pin 3 | |
| MISO | 19 | pin 4 | |
| SCLK | 18 | pin 2 | SPI mode 3 (CPOL=1, CPHA=1) |
| CS | 5  | pin 5 | manual/software chip-select |
| INT1 | 2  | pin 6 | hardware trigger out (`CHIRP_SENSOR_TRIG_PIN=1`); open-drain, 2.2k pull-up |
| INT2 | 4  | pin 7 | data-ready interrupt in (`CHIRP_SENSOR_INT_PIN=2`); open-drain, 2.2k pull-up |

VDD = 1.8V regulated; VDDIO may be 3.3V (direct to the ESP32).

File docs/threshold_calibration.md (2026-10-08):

# Receiver detection threshold calibration

The pitch-catch receiver's `icu_gpt` algorithm reports the first sample whose magnitude crosses a
piecewise-constant threshold: 8 `{start_sample, level}` segments (`ch_thresholds_t`,
`CH_NUM_THRESHOLDS` = 8). This page describes how the table in
`src/components/sensor_calibration/rx_thresholds.c` (`sc_rx_thresholds`) was derived from bench
recordings.

## Data

The current table comes from `src/apps/pitch_catch_mode_hardware_test/readouts/parsed/`. These are
the 2026-10-07 hardwired pitch-catch captures; they are local only (gitignored) and were extracted
with `extract_measurements.py --odr 5`. There are 700 raw I/Q readings in 14 batches of 50:

| Distance | Batches |
|---|---|
| 0.5 m | straight |
| 1.5 m | straight, 30° TX, 45° TX, 45° RX |
| 3 m | straight, 30° TX, 45° RX |
| 4 m | straight, 30° TX, 30° RX |
| 5 m (4990 mm) | straight, 30° TX, 30° RX |

"TX" and "RX" name which board was turned. The data set is incomplete: the plan is to cover both
boards turned up to 45° at every distance.

Capture settings, from `sensor_calibration.h` (`src/components/sensor_calibration/include/`):
- **TX burst:** 450 µs at pulse width 4. That is about 640 sensor clock counts, which AN-000175
  Table 5 gives as the minimum to fully excite the transducer.
- **ODR:** f_op/4 (ODR 5), with op freq 88521 Hz.
- **Ringdown cancel:** 20 samples. Each reading has 339 samples.

An earlier table (2026-10-05) was fitted to 80 µs bursts at f_op/8. It is superseded, because both
the sample spacing and the signal strength changed.

**Distance to sample.** In pitch-catch the sound crosses the gap once:
`mm/sample = 343000 · 2^(7−ODR) / op_freq`, which is **15.5 mm/sample** here.
- **Pulse shape.** The received pulse ramps up for about the burst length (10 samples, 155 mm) and
  peaks at about the predicted index (+0.4 samples).
- **Arrival positions.** The script finds each batch's arrival from its median waveform. Every batch
  is within ±2 samples of its predicted index, except **5 m, which arrives 6 samples (~93 mm)
  early**. Either that distance was really about 4.9 m, or something else is going on there. The
  table uses the measured arrival positions, so it isn't thrown off either way.

## Method

The method is implemented in
`src/apps/pitch_catch_mode_hardware_test/receiver_readout/host/calibrate_thresholds.py`, which uses the
standard library only.

1. **Peaks and noise.**
   - Direct-path peak: the largest |I,Q| within ±4 samples of the batch's arrival.
   - Noise floor: every sample from the end of the ringdown up to the start of the pulse's ramp. This
     is where a noise crossing would become a false first target. The noise has a median of 14,
     p99.9 of 43 and a maximum of 59.
   - Later reflections don't matter here. With `num_ranges = 1` only the first crossing is reported,
     and the direct path is first.
2. **45° gate.** A batch with `45deg` in its title is fitted only if its SNR is at least
   `--min-snr` (default 2). SNR here means the weakest-1% peak divided by the noise maximum.
   - In the 2026-10-05 data, 4 m at 45° (SNR 1.3) was excluded this way.
   - In this data set every 45° batch passes: 1.5 m at 22–23, 3 m RX at 9.1.
   - `--include-45` fits every 45° batch regardless of SNR.
3. **Threshold units.** The sensor compares its own CORDIC magnitude against the threshold
   (`structs.h`: "Cordic_mag(I,Q) must exceed this level"), not hypot(I,Q) of the read-out data.
   - The scale `k` (|I,Q| per threshold unit) is fitted from the batches where the recording table
     caught some readings but not all. In a batch where the firmware detected a fraction f, the
     effective threshold is the (1−f) quantile of its peaks.
   - The fits were 1.44 (3 m 45° RX, 8/50 hits) and 1.50 (4 m straight, 2/50 hits). The 2026-10-05
     data gave 1.45–1.70.
   - The largest value, **k = 1.50**, is used, because it gives the lower and safer levels.
4. **Worst-case envelope.** For each distance, take the 1st-percentile peak of the weakest batch,
   placed at its measured arrival:

   | Distance | Weakest batch | Peak (p1) |
   |---|---|---|
   | 0.5 m | straight | 11837 |
   | 1.5 m | 45° RX | 1295 |
   | 3 m | 45° RX | 540 |
   | 4 m | 30° RX | 223 |
   | 4.9 m | 30° RX | 188 |

   Interpolate log-linearly between points, and extrapolate beyond the ends.
5. **Segments and levels.**
   - Segment 0 covers the ringdown window. Its level is high because those samples are cancelled.
   - Segments 1–7 split the range from the end of the ringdown (sample 20) to the point where the
     level reaches the noise floor. Each segment spans an equal drop in the envelope.
   - Level = 0.5 (−6 dB) × the envelope at the segment's far end / k.
   - Floor = 2 × noise max / k, which is 118 |I,Q|. Levels never rise with distance.
   - The last segment holds the floor out to 5 m and beyond.
6. **Replay.** Both tables are run on every reading: first index at or after the ringdown with
   |I,Q|/k ≥ level. A detection is counted as correct anywhere from the start of the ramp
   (peak − 14) to peak + 4. Any other detection is counted as false.

## Result

| start_sample | from (mm) | level | ≈ \|I,Q\| |
|---|---|---|---|
| 0 | — (ringdown) | 4075 | 6099 |
| 20 | 303 | 3326 | 4978 |
| 39 | 598 | 1785 | 2671 |
| 57 | 877 | 958 | 1434 |
| 75 | 1156 | 514 | 769 |
| 93 | 1435 | 275 | 412 |
| 148 | 2287 | 147 | 220 |
| 209 | 3232 | 78 | 117 |

The near segments are packed closely because the signal falls about 9× between 0.5 m and 1.5 m.

**Replay.** The new table detects every reading (50/50) in all 14 batches, with 0 false
detections. That includes 5 m at 30° TX and 30° RX. The recording table (the old 5-segment
placeholder) caught nothing at 4–5 m except 2/50 at 4 m straight.

**Effect of the longer burst** (450 µs, PW 4, compared with 80 µs, PW 3, on 2026-10-05). These are
straight-on median peaks. Not every gain comes from the burst: some come from the different ODR and
receive filter, which also scale the I/Q values.

| Distance | 2026-10-05 | 2026-10-07 |
|---|---|---|
| 3 m | 708 | 1162 |
| 4 m | 299 | 449 |

At 5 m the weakest batch's SNR is 3.2. With the old burst, off-axis 5 m was extrapolated to an SNR
of about 1.

**Caveats:**
- The 5 m arrival is 93 mm early; re-check that distance.
- Detection fires on the pulse's rising edge, up to 10 samples (155 mm) before the peak. So
  `range_mm` depends on signal strength as well as distance. This is a ranging-accuracy issue, not a
  detection issue.
- The table is untested on hardware until an app adopts it.

## Re-running and using it

```sh
cd src/apps/pitch_catch_mode_hardware_test
./receiver_readout/host/calibrate_thresholds.py --dry-run          # report only
./receiver_readout/host/calibrate_thresholds.py                    # rewrite rx_thresholds.c
./receiver_readout/host/calibrate_thresholds.py path/to/parsed --tx-us 450 --margin 0.5 --noise-mult 2
```

Options that must match the capture conditions, or the fit will be wrong:
- `--old-threshold START:LEVEL` (repeatable): the table the recordings were captured with. If it is
  wrong, `k` will be wrong.
- `--tx-us`: the sender's `PC_TX_PULSE_US`.
- `--ringdown-samples`: the receiver's ringdown cancel.

To adopt the table in an app:
1. Add `sensor_calibration` to the app's `main/CMakeLists.txt` `REQUIRES`.
2. `#include "sensor_calibration.h"`.
3. Pass `&sc_rx_thresholds` to `icu_gpt_algo_configure()` in place of the local `rx_thresholds`.

The table assumes the capture conditions in the same header: `PC_ODR` (ODR 5), `PC_TX_PULSE_US`
(450 µs) and `SC_RX_THRESHOLDS_RINGDOWN_SAMPLES` (20). If any of them changes, regenerate it.

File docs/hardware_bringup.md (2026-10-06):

# Hardware bring-up

App: `src/apps/echo_mode_hardware_test` (ESP-IDF; renamed from `hardware_bringup` once the POST
and echo/pulse-echo rangefinding loop were both verified working, to distinguish it from the
sibling `pitch_catch_mode_hardware_test`). See `src/apps/echo_mode_hardware_test/README.md` for
the full API / build reference; this doc is the higher-level explanation and the current status.

## Purpose

Bring up the EV_MOD_ICU-20201 ultrasonic module wired to an ESP32 DevKitV1, on top of the
SonicLib board support package in `src/components/soniclib_esp32_bsp`. The first deliverable is a
**power-on self-test (POST)** that verifies the ESP32 can talk to the sensor over SPI.

## Power-on self-test

The `icu_post` component (`src/components/icu_post/`, `icu_post.{c,h}`) - a reusable,
SonicLib-level module (no direct esp-idf calls beyond `esp_log`) so any app can call `post_run()`
at boot regardless of BSP or wiring changes. All hardware access goes through the `chbsp_*`
callbacks the BSP implements. See `src/components/icu_post/README.md` for the API summary and
`docs/icu_post.md` for the full stage-by-stage reference.

| Stage | Call | Pass means |
|---|---|---|
| 1. SPI link | raw `CPU_ID_HI` read + `chdrv_prog_ping()` | Resets the sensor via its `SYS_CTRL` register and reads the `CPU_ID_HI` debug register back over SPI, checking it equals `SHASTA_CPU_ID_HI_VALUE` (`0x2041`). The raw value is logged first (`0x0000` = unpowered/no MISO, `0xFFFF` = MISO floating, stable-wrong = SPI mode/bit-order/timing). Proves wiring, chip-select, **SPI mode 3**, bit order and framing end to end. The headline "ESP32 can talk to the module" check. |
| 2. Program + start | `ch_group_start()` then `ch_sensor_is_connected()` | Firmware downloads to the sensor, frequency locks, RTC calibrates. |
| 3. Sensor identity | `ch_get_part_number` / `ch_get_sensor_id` / `ch_get_fw_version_string` / `ch_get_frequency` / `ch_get_rtc_cal_result` | Programmed sensor reports sane values - part `20201`, operating frequency ~85 kHz (70-95 kHz per DS-000478; outside 65-100 kHz fails), non-zero RTC cal. |

`main/post_main.c` is the bring-up harness (`app_main`): `ch_group_init` -> `ch_init` ->
`chbsp_esp32_init` -> `post_run` -> `post_report`, retrying every 5 s on failure. Once the POST
passes it hands off to the rangefinding loop below. Not the production entry point.

## Rangefinding loop

`main/rangefinder_loop.{c,h}` - after the POST passes, `rangefinder_run()` configures the sensor
and streams distance to the console:

1. `ch_meas_init()` (ODR = fop/8) + `icu_gpt_algo_init()` / `icu_gpt_algo_configure()` (1 target,
   ringdown cancel, detection thresholds).
2. Measurement queue: `ch_meas_add_segment_tx()` (burst) -> `ch_meas_add_segment_count()`
   (settle) -> `ch_meas_add_segment_rx()` (listen, done-interrupt on the last segment) ->
   `ch_meas_write_config()`; then `ch_set_algo_config()` / `ch_init_algo()`.
3. `ch_set_max_range(5000)` (5 m one-way, trims the RX sample count),
   `ch_set_freerun_interval(100)` (10 Hz), `ch_set_mode(CH_MODE_FREERUN)`.
4. Data-ready: the BSP's `bsp_int_task` calls the registered callback (`ch_io_int_callback_set`)
   at task level; it does `ch_get_range(dev, CH_RANGE_ECHO_ONE_WAY)` (single sensor, pulse-echo)
   and hands the value to the print loop. `ch_get_range()` returns millimetres x 32, or
   `CH_NO_TARGET`.

The transmit/receive/threshold values in `rangefinder_loop.c` are bring-up starting points and
will likely need tuning on the bench (each `#define` has a note). The 5 m range and 10 Hz
interval are fixed by the requirement.
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

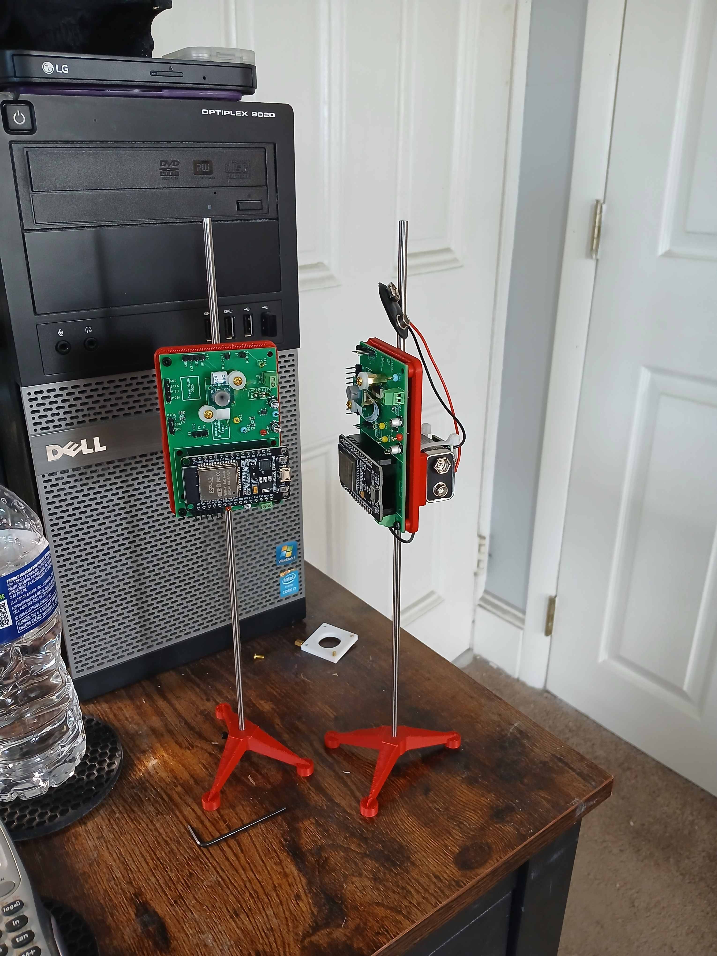
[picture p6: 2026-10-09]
pics/Testing/stands.jpg

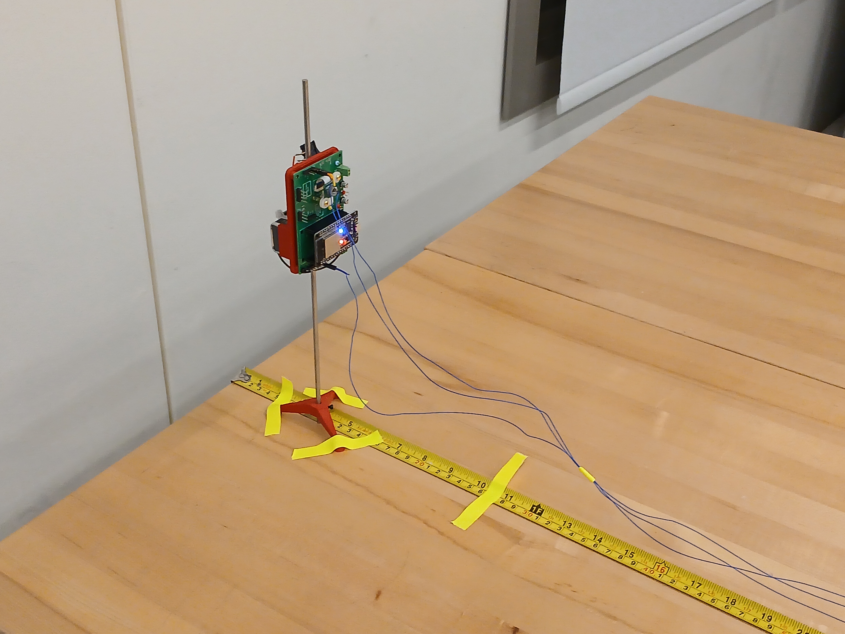
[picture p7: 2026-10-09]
pics/Testing/transmitter.jpg

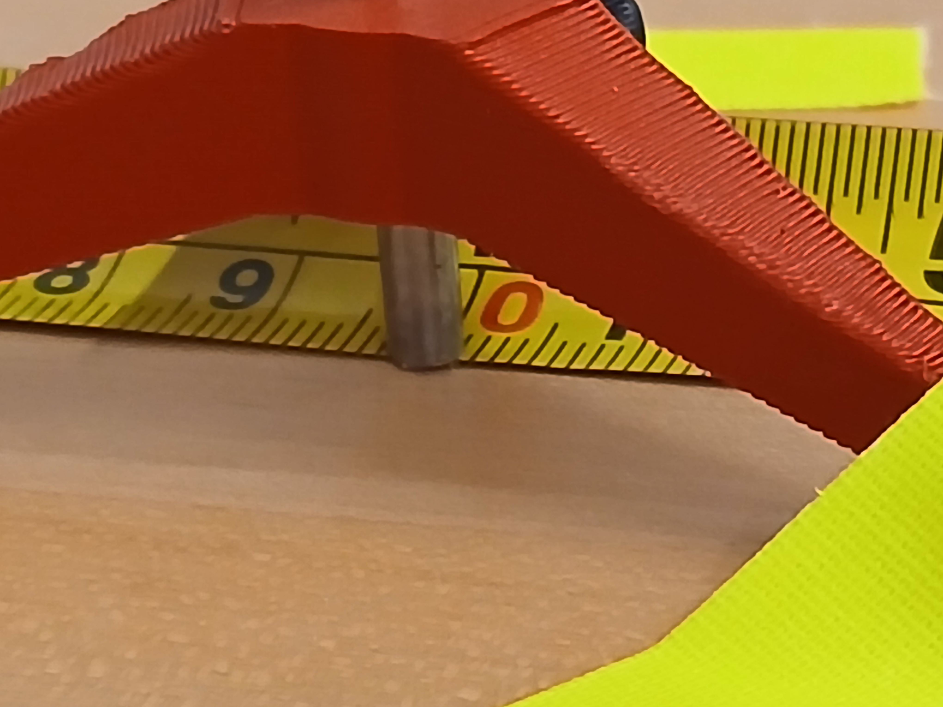
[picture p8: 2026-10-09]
pics/Testing/measurement.jpg

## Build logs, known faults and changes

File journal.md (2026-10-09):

# Project Journal
This doc is for briefly summarizing daily progress/thoughts/setbacks for future reference

## 10-9-2026
- Added `src/components/sensor_calibration/include/sensor_offsets.h` with `TRANSMITTER_OFFSET` / `RECEIVER_OFFSET` (23.25 mm each), the distance from each transducer to the base of its unit, where the actual distance is measured. The two-pass `receiver_readout` now adds both to every printed `range_mm`. The band/gate choice still uses the uncorrected range, since the fine window is in the sensor's time base. Builds clean.
- The two-pass `receiver_readout` now prints only the sensor's distance for the coarse pass, with no I/Q. Only the fine pass's I/Q is read and dumped, which also shortens the gap between the two chirps. `extract_measurements.py` writes no CSV for blocks without I/Q rows.
- Switched the two-pass coarse pass from the old placeholder thresholds to the calibrated `sc_rx_thresholds`, pulled from the `sensor_calibration` component (no local copy). Its ringdown cancel now comes from `SC_RX_THRESHOLDS_RINGDOWN_SAMPLES`. The fine-pass `coarse_mm` is now printed to 0.1 mm. Builds clean.

## 10-8-2026
- Implemented the two-pass pitch-catch readout (`src/apps/two-pass_pitch_catch_test/receiver_readout/`). The sender is unchanged; the receiver triggers it twice per reading. The two passes use the ICU's two measurement slots: meas 0 is the coarse f_op/4 pass, meas 1 the fine f_op/2 pass. Before each fine pass, the fine slot's count segment is lengthened by a 0 / 1.25 / 2.5 m pad (band picked from the coarse range), and its thresholds become a gate around the coarse distance. Both passes' I/Q are dumped. The host scripts now understand the new `pass=` line and the `--pad-mm` axis shift. Builds clean; not yet run on hardware.
- Found in SonicLib that the pad should already be compensated: RX-only count segments are counted as pre-RX time, and `icu_gpt` adds that back into the time of flight. Needs hardware confirmation.
- Gotchas: `ch_get_num_samples()` only reports meas 0, and `ch_meas_insert_segment()` at index 0 reads out of bounds (so the pad is set by editing the instruction length directly). The fine gate level is a placeholder until f_op/2 captures exist.

## 10-7-2026
- Moved the locked-down sensor config (`PC_TX_PULSE_US`, `PC_TX_PULSE_WIDTH`, `PC_TX_PHASE`, `PC_ODR`, `PC_MAX_RANGE_MM`) out of the apps' local `pitch_catch_common.h` into `src/components/sensor_calibration/include/sensor_calibration.h` (alongside the threshold table, replacing its duplicate `SC_RX_THRESHOLDS_ODR`/`_TX_US` defines), so new apps pull the current values via `REQUIRES sensor_calibration`. The trigger timing and sender-ready GPIO stay in each app's local `pitch_catch_common.h`, which now includes `sensor_calibration.h`. `pitch_catch_mode_hardware_test` and `two-pass_pitch_catch_test` both switched over; all six apps build.
- Calibrated the receiver's detection thresholds from the 2026-10-05 captures (2400 readings, 1-4 m,
  straight / 30° / 60° / 45°). The old placeholder table missed almost everything past 1 m (0/250
  at 3 m and 4 m straight). New `calibrate_thresholds.py` fits a worst-case amplitude envelope and
  writes an 8-segment table to the new `src/components/sensor_calibration/` component. Replayed on
  the recordings, it detects every reading in every fitted batch with no false detections. The
  45° batches at 1-3 m are included in the fit. 4 m 45° is discarded, because its peak is only 1.3x
  the noise. Not yet used by any app
  or tested on hardware. Write-up in `docs/threshold_calibration.md`.
- Lengthened the pitch-catch TX burst from 80 us (~113 SMCLK counts, ~1/6 of the ~640 that AN-000175
  says fully excites the MEMS) to 450 us. Raised the pulse width from 3 to 4 (max drive). Switched the
  shared ODR to f_op/4. `sender` and `receiver` rebuild clean. Not yet flashed, and the new threshold
  table must be regenerated for the new ODR.
- Re-recorded with the new burst: 700 readings at 0.5-5 m, straight, 30° and 45°, turning either the
  TX or the RX board. The signal is much stronger (3 m straight p50 1162 vs 708). The script now finds
  each batch's arrival from the data and allows for the burst's 10-sample ramp-up. Regenerated
  `sc_rx_thresholds`. Replay detects 50/50 in all 14 batches, including 5 m at 30°, with 0 false
  detections. The 5 m pulse arrives ~93 mm early, so that tape distance needs re-checking. The
  data set is still incomplete: the full 45° sweep for both boards is still to come.

## 10-5-2026
- Reworked `pitch_catch_mode_hardware_test/receiver_readout` for batch data collection. The
  console prompts for a batch title, the actual distance (mm) and a reading count, waits for
  Enter, then dumps that many readings back-to-back, each as a `BEGIN`/`END` block that starts
  with the title and actual distance. Failed readings still get a block (an `error=` line), so a
  batch always has N blocks. Before each trigger the receiver now waits up to 100 ms for the
  sender-ready line (GPIO33) instead of skipping at once. Reused the IR app's echoing console
  helper and added a text-line reader. `extract_measurements.py` now parses the new blocks and
  writes a `manifest.csv` (title, actual vs. measured range, file). It still reads old captures.
  After configuring, the receiver reads the measurement queue back from the sensor and logs the ODR
  it will actually use, warning if it differs from `PC_ODR`. Builds clean; not yet run on hardware.
- First run of the new receiver_readout: the receiver's sensor reported an operating frequency of
  1 Hz. That's SonicLib's error code: the PMUT clock count during startup came back ~0, while the
  CPU-clock count, RTC calibration and SPI were all fine. The firmware is unchanged from the
  earlier good captures (323 samples), so this looks like a sensor/board problem. Still being
  diagnosed. The POST only warned about it, so the app carried on with a 1-sample configuration.
  `icu_post` now fails the identity stage when the frequency is outside 65-100 kHz.
- Fixed `plot_readout.py` (both the pitch-catch and IR copies) reporting half the real distance:
  it used SonicLib's pulse-echo sample-to-mm formula, which halves the round trip. In pitch-catch
  the sound crosses once, so the full time of flight is the distance (as in the firmware's
  `CH_RANGE_DIRECT` range_mm). HTML plots generated before this show half-scale distances.
- `extract_measurements.py` takes `--op-freq` / `--odr` and records them in every `manifest.csv` row,
  since both set the sample spacing and so the accuracy of any distance derived from the I/Q.

## 10-2-2026
- Added a console menu to `ir_accuracy_test/receiver` (`m` returns to it): (1) an IR timing tuner
  that sets an optional pre-burst (carrier on/off, in us) and the trigger-burst length, with Space
  firing test triggers for the scope; (2) the existing raw I/Q readout, whose `IQ_BEGIN` line now
  also records the IR timing; (3) one-shot distance readings (`RANGE` lines). Switched the IR
  waveform from LEDC + busy-wait (~26 us granularity) to the RMT peripheral's carrier modulator,
  so the whole waveform is hardware-timed to 1 us. Builds clean; not yet run on hardware.

## 9-28-2026
- `src/apps/ir_accuracy_test` run on hardware and **passed**: the receiver's 38 kHz IR burst
  triggers both sensors through their demodulators with no board-to-board wires, and the receiver
  dumps the I/Q trace. This is the first working wireless trigger for pitch-catch. Next: measure
  the trigger skew between boards on the scope and compare range accuracy against the hardwired
  captures.
- Confirmed signal polarity: the IR LED idles low (off), and the demodulator output and the ICU's
  INT1 trigger are both active-low. So INT1 fires as soon as the IR burst is received (the
  burst-start edge), and the 5 ms burst length doesn't affect trigger timing.
- (9-26) Both apps now drive GPIO26 high at the very start of `app_main()`, before POST, to power
  the IR module (`ir_power_on()` in `include/ir_common.h`).
- Designed-in a precision 32.768 KHz oscillator to clock both the ESP32 and ICU-20201 for improved
  accuracy in distance measurements. 
- Started cleaning up some of the documentation. Some of it is outdated and abandoned, some just straight up
  missing. Work not done here. 

## 9-25-2026
- Added `src/apps/ir_accuracy_test/{sender,receiver}`: the pitch-catch raw I/Q readout with the
  hardwired INT1 trigger and GPIO33 sender-ready wires replaced by an IR link. The receiver fires a
  5 ms, 38 kHz (LEDC, 50% duty) burst on GPIO25; each board's IR demodulator drives its own
  sensor's INT1, so both sides see the same demodulator latency. Both apps release ESP32 GPIO2
  (INT1) to high-impedance so it can't fight the demodulator, and never call SonicLib's trigger
  functions. Sensor config and the `IQ_BEGIN`/`IQ,`/`IQ_END` dump are unchanged from
  `receiver_readout`, so the host scripts work as-is. Both apps build clean; not yet run on
  hardware.

## 9-24-2026
- Added `src/apps/pitch_catch_mode_hardware_test/receiver_readout/`, a raw I/Q dump variant of
  `receiver/` for offboard signal processing / bench tuning. Same sensor configuration as
  `receiver_loop.c` (measurement queue, `icu_gpt` algo/thresholds, `CH_MODE_TRIGGERED_RX_ONLY`),
  but on-demand rather than free-running: a full I/Q dump (up to `ICU_MAX_NUM_SAMPLES` samples x
  4 bytes, ~1.4 KB) doesn't fit inside the base receiver's 100ms trigger interval over a typical
  console baud rate, so this app idles for a line typed on the serial console, fires exactly one
  trigger, and dumps that measurement's raw I/Q trace as plain text
  (`IQ_BEGIN`/`IQ,<idx>,<i>,<q>`/`IQ_END`). Deliberately plain text, not a binary/COBS protocol
  like `automated_tuning`'s - no host-side parser exists yet, this is meant as a quick bench tool.
  Builds clean in the Docker toolchain; not yet run on hardware.

## 9-17-2026
- Implemented the `automated_tuning` host control script (`host/tuner.py`, `serial_link.py`,
  `trial.py`, `tuning_search.py`, `cobs.py`) plus a pytest suite (31 tests, all hardware-
  independent: COBS round-trip, frame demuxing including the interleaved-telemetry case, trial
  statistics/scoring, the sample-index formula, JSON schema round-trip). Set up a venv +
  `requirements.txt` under `host/` per usual convention.
- Found and fixed a real firmware bug while implementing the host script (not on hardware yet):
  `AT_OP_ADD_SEGMENT_*` conflated "apply to the receiver's own sensor" with "relay to the
  transmitter" into a single shared array - the transmitter could never have received a working
  TX segment, since the receiver is RX-only and the transmitter needs TX+COUNT+RX. Fixed by
  adding an explicit `target` (LOCAL/REMOTE) field to the three segment opcodes
  (`AT_PROTOCOL_VERSION` bumped 1->2). Both firmware images rebuilt clean.
- First live hardware test of the whole system: hit a hang on `AT_OP_SET_MAX_RANGE`, every time,
  right after `AT_OP_GPT_ALGO_CONFIGURE` succeeded. Two theories (a SonicLib segment-shrink loop
  in `ch_common_meas_set_num_samples`, and an uninitialized-measurement corruption from calling
  `ch_meas_reset()` before any `ch_meas_init()`) were both ruled out by reading the vendored
  SonicLib source directly - both turned out to be pure host-side RAM operations with no
  possibility of hanging.
- Actual root cause, found by reading `at_cfg_meas_reset()` closely: it called
  `xSemaphoreTake(g_trigger_cycle_mutex, ...)` but never checked the return value, so a timed-out
  acquisition still fell through to call `ch_set_mode()`/`ch_meas_reset()` on the sensor without
  actually holding the lock - racing directly against the trigger loop's own in-flight SPI
  activity. Fixed by checking the return value and returning `AT_STATUS_ERR` on timeout instead.
- Added temporary debug instrumentation to confirm the fix: `rpc_dispatch.c` prints
  `[dbg] opcode=... enter/exit` around every RPC call via `esp_rom_printf`, wrapped in explicit
  `0x00` delimiters (`dbg_print()`) so it can't corrupt the real COBS-framed response that
  follows it on the wire - the first version of this without NUL-wrapping did exactly that,
  breaking even the `HELLO` handshake. `serial_link.py`'s reader was temporarily changed to print
  any bytes that fail to parse as a frame, so the breadcrumbs are visible from `tuner.py`.
- Reflash-and-retest confirmed the semaphore fix: the full reconfigure sequence (11 opcodes) now
  completes cleanly with `status=0` on every call, across all three Stage 1 ODR candidates - no
  hang. Also surfaced an unrelated, lower-priority finding: SonicLib's own `CH_LOG_INFO` logging
  (`CH_LOG_MODULE_LEVEL=2`) bypasses `esp_log_level_set()` entirely and leaks onto the wire
  regardless of our "UART0 belongs to the RPC link" design - COBS resync handles it today, but
  worth tightening later.
- New problem, not yet resolved: with the hang fixed, the search runs but reports
  `detection_rate=0.00` at a 250mm test distance - right at the edge of the ICU-20201's ~200mm
  rated minimum range. Receiver's own trigger loop/local config confirmed healthy (telemetry
  flows every trial); undetermined whether this is a near-field limitation of the seed config or
  an unvalidated wiring/ESP-NOW-pairing issue (this receiver+transmitter pair, on any firmware,
  has never been confirmed to produce a valid pitch-catch reading - see TODO.md).
- Paused here (mid-debug) to switch to another project. Temporary debug prints are still in the
  tree; see TODO.md for the exact resume plan.
- Scaffolded `src/apps/espnow_ftsp_test/` (previously an empty README-only stub) into a working
  first-pass FTSP-over-ESP-NOW capability test. Single symmetric app - both boards run identical
  firmware and elect a root by lowest MAC address at boot, rather than the sender/receiver split
  used by `pitch_catch_mode_hardware_test`. `ftsp_sync.c` fits a real least-squares regression of
  clock offset vs. local time from each root SYNC beacon; `gpio_strobe.c` uses `esp_timer` (not
  `vTaskDelay`) to strobe GPIO25 on 100ms boundaries of the synchronized root clock, re-deriving
  the deadline from the freshest fit every cycle. Builds clean in the Docker toolchain; not yet
  run on hardware - see TODO.md for the bench-tuning list.
- First on-hardware run of `espnow_ftsp_test`: both boards strobe GPIO25, but with a severe and
  variable delta between the two edges (one scope measurement: 8ms). Too large to be clock-skew
  drift and too variable to be a fixed-offset bug, which pointed at a jitter source. Root cause:
  `espnow_link_init()` never disabled WiFi power save, so STA mode defaulted to
  `WIFI_PS_MIN_MODEM` - sleeps the radio between operations and wakes it on demand, a known source
  of multi-ms variable latency on `esp_now_send()`/recv-callback dispatch that directly corrupts
  every FTSP timestamp (all taken at the API call site). Added `esp_wifi_set_ps(WIFI_PS_NONE)`.
  Builds clean; re-test on hardware is next (see TODO.md).
- Reflashed both boards with the power-save fix plus new per-packet reception logging. Confirmed
  the radio link and election are solid - both boards' logs showed a continuous, bidirectional
  stream of received HELLO/SYNC packets and correct election (`role=FOLLOWER, root=<the other
  board's MAC>` on one side, matching `role=ROOT` on the other). Not a communication problem.
- Found the real cause of the remaining severe/variable strobe delta in the follower's own sample
  log: 3 of 4 early SYNC samples clustered tightly (~366us spread), but one was a ~13ms outlier -
  and it landed as one of only 2 points in the regression right when `gpio_strobe` started
  trusting the fit. A 2-point line fits both points exactly, so that single bad sample became the
  entire skew estimate - exactly the gap already flagged in the design doc (no outlier rejection).
  Fixed: raised the minimum sample count before a fit is trusted
  (`FTSP_MIN_SAMPLES_FOR_VALID`, 2->4) and added residual-based outlier rejection against the
  existing fit (`FTSP_OUTLIER_THRESHOLD_US=3000`) in `ftsp_regression_add_sample()`. Builds clean;
  re-test on hardware is next.
- Added a compile-time logging mute (`CONFIG_FTSP_MUTE_LOGS` via a new `main/Kconfig.projbuild`)
  to test whether blocking UART writes, not WiFi, were the dominant jitter source - each console
  line costs several ms of real wall-clock time, long enough to delay FreeRTOS scheduling and
  corrupt the `esp_timer_get_time()` calls this app depends on. Verified via `strings` on the
  built `.elf` that enabling it genuinely strips the log format strings at compile time.
- Redesigned the strobe rendezvous per a design change requested mid-session: instead of each
  board independently rounding its own clock estimate up to the next 100ms boundary, the root now
  explicitly picks and broadcasts the next strobe instant in every SYNC packet
  (`next_strobe_root_us`), and followers copy it verbatim rather than re-deriving it - moves the
  "which boundary is next" decision onto the root's own, definitionally-accurate clock instead of
  a follower's noisier real-time estimate. Old independent-derivation logic kept as a fallback for
  when no fresh announcement is available yet. Also matched `FTSP_SYNC_INTERVAL_MS` to the strobe
  period (200->100ms) so a fresh announcement covers every strobe cycle. Builds clean both with
  and without logging muted; re-test on hardware (all three fixes together) is next.

## 9-11-2026
- Implemented `src/apps/pitch_catch_mode_hardware_test/{sender,receiver}` (previously an empty
  scaffold). Both build clean independently in the Docker toolchain; not yet run on hardware.
- Key design decision, settled through discussion before writing code: the **receiver** owns the
  periodic trigger loop (`ch_group_trigger()`), not the sender - inverts SonicLib's "typical"
  AN-000175 pattern. The receiver is the fixed beacon and knows its own trigger instant exactly
  (no communication latency), which matters for time-of-flight. The sender never calls any
  trigger function; it configures `CH_MODE_TRIGGERED_TX_RX` once and idles.
- Added a second physical link, sender's INT2 (data-ready) -> receiver's GPIO33, so the receiver
  can check the sender is actually done with its previous measurement before retriggering, instead
  of firing blind on a fixed timer. Read directly via `driver/gpio.h`/`esp_driver_gpio`, not
  through the BSP (which is scoped to a board's own local sensor).
- Source-verification correction while planning: `CH_MODE_TRIGGERED_TX_RX` is not TX-only - per
  AN-000175 the sender still listens for its own echo, so its measurement queue needs a full
  TX+settle+RX segment set, same shape as the echo-mode app. The receiver, being RX-only, uses a
  count segment (sized to match the sender's TX burst duration) instead of a TX segment.
- Added `include/pitch_catch_common.h`, a header shared by both independent app builds
  (`INCLUDE_DIRS "../../include"`), holding every cross-board-critical constant (TX burst timing,
  ODR, max range, trigger cadence, the GPIO33 pin) as a single source of truth, instead of
  hand-synced `#define`s that could silently drift apart.
- Deferred (documented in the new README and TODO.md, not implemented): frequency matching and
  `ch_set_rx_pretrigger()` across the two independently-calibrated sensors - both only work within
  one shared `ch_group_t`, which doesn't exist across two separate boards.
- Next: get both boards on the bench, verify INT1/GPIO33 wiring continuity, tune RX gain/
  thresholds per sensor, and validate `CH_RANGE_DIRECT` against a tape-measure baseline.

## 9-10-2026
- The free-running echo-mode rangefinding loop ran successfully on real hardware - POST + rangefinding both verified working end to end.
- Renamed `src/apps/hardware_bringup` -> `src/apps/echo_mode_hardware_test` and added a `src/apps/pitch_catch_mode_hardware_test/{sender,receiver}` scaffold for the next milestone (two-sensor triggered pitch-catch). Docs/TODO/CLAUDE.md paths updated to match.

## 9-6-2026
- Housekeeping: restructured the repo into `src/components/` (invn-soniclib, soniclib_esp32_bsp, icu_post) + `src/apps/hardware_bringup/`; dropped ~1400 committed build artifacts from git. Docs/paths updated. Builds verified.
- Wrote the free-running rangefinding loop (`src/apps/hardware_bringup/main/rangefinder_loop.c`): builds a measurement queue, configures icu_gpt algo + thresholds, `ch_set_max_range(5000)`, `ch_set_freerun_interval(100)`, `ch_set_mode(CH_MODE_FREERUN)`, prints `ch_get_range()` from the data-ready callback. Builds clean; not yet run on hardware. TX/RX/threshold values are starting guesses to tune on the bench.
- BSP interrupt refactor: GPIO ISR now only notifies a dedicated task (`bsp_int_task`) which calls `ch_interrupt()` at task level; removed `USE_DEFERRED_INTERRUPT_PROCESSING`. This is the proper fix for the earlier "SPI in ISR context" watchdog panic and makes the runtime data-ready callback work.

## 9-5-2026
- Fixed FFC cable wiring problem (all pins mirrored- 12 should be 1, 11 should be 2, 10 should be 3, etc) and got POST running and passing successfully
- The BSP (`src/soniclib_esp32_bsp`) and the power-on self-test (`src/hardware_bringup`) build
cleanly. USB cable issue (2026-09-03) resolved. FFC pinout in the datasheet was wrong - pins had to be
reversed (1<->12, 2<->11, ...); after rewiring, stage 1 (SPI link) PASSES (CPU ID 0x2041, device
found, firmware programmed). See `docs/hardware_bringup.md`.
- Then hit an `Interrupt wdt timeout ... running in ISR context` during firmware start. Cause: the
BSP GPIO ISR calls `ch_interrupt()`, which (without `USE_DEFERRED_INTERRUPT_PROCESSING`) ran the
SPI-heavy `chdrv_int_callback_deferred()` inline in ISR context -> blocking `spi_device_transmit()`
deadlock. Fixed by adding `USE_DEFERRED_INTERRUPT_PROCESSING` to `invn-soniclib/CMakeLists.txt`
(2026-09-05). Re-flash and continue from stage 2.

## 9-3-2026
- Started hardware bring-up. Had Claude write a reusable power-on self-test (`src/hardware_bringup`) that checks SPI comms to the ICU-20201 via SonicLib `chdrv_prog_ping()`, then `ch_group_start()`, then an identity read-back. Builds clean. Also fixed the BSP SPI mode (0 -> 3, per DS-000478 / AN-000357) and swapped the INT1/INT2 roles (INT1 = trigger, INT2 = data-ready).
- Setback: could not flash the ESP32 - USB serial link is unreliable (esptool reaches the ROM but flash writes abort mid-transfer, boot log comes back with bytes duplicated ~80x). Board is fine (boots factory ESP-AT off 4MB flash). Almost certainly a bad USB cable; no spare on hand. Resuming once a cable is available - see `TODO.md` / `docs/hardware_bringup.md`.

## 7-22-2026
- Designed a circuit that can function as either master or slave beacon, designed the PCB, and ordered that + parts. Waiting on board and parts. Next step is to bring up the hardware and do a hardware test of the board support package

## 7-8-2026
- Had Claude assist in writing the SonicLib board support package for the ESP32 Devkit V1. This is the intermediate layer between the high-level SonicLib business logic and the low-level ESP32 hardware, basically the driver to control the pins and timers. It is NOT tested in hardware yet, although it is verified to build successfully. Also had claude write `docs/board_support_package.md` and update `TODO.md` with next steps for testing the BSP

## 7-5-2026
- Revised the test rig to use the newer ICU-20201 ultrasonic chip instead of the CH201. Redesigned the test rig so that each sensor has its own ESP32 for the sake of convenience and not running a ton of long wires

## 6-24-2026
- Finished and uploaded schematics for a CH201 test rig. Two CH201's operate in pitch-catch mode, controlled by an ESP32. Hardware has yet to be built and I still need to write the ESP32 firmware

## 6-2-2026
- Created this GitHub account

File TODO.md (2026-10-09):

# To - Do

## General housekeeping + Documentation
- [ ] Update and clean up this to-do. Lots of now-irrelevant details.
- [ ] Add schematic for the IR triggering circuit.
- [ ] Add schematic for the buffered 32.768KHz clock oscillator
- [x] Remove the obsolete wireless sync testing and auto-calibration tests
- [x] Move the shared sensor config (TX burst, ODR, max range) to `src/components/sensor_calibration/include/sensor_calibration.h`
- [ ] Switch `ir_accuracy_test/include/ir_common.h` to `sensor_calibration.h` - it still defines its own
	  older `PC_*` values (80 us burst, width 3, `CH_ODR_DEFAULT`)
- [ ] Revise the documentation to reflect new change in project scope, that being that we are now
	  only concerned with 2-dimensional positioning for this proof of concept. 
- [ ] Get website launched to document the process in more detailed writeups of each stage. 
- [ ] Write up final research paper detailing the entire project: motivation, theory of operation, hardware design,
	  software design, next steps, etc.

## Hardware Design & testing
- [ ] Bench-test to verify that clocking the ESP32 externally via GPIO33 works. 
- [ ] Change the terminology used on the solder bridges
- [ ] Add red/green LEDs for indicating operational status (power-on self-test result, runtime errors, etc)
- [ ] Design and test a new version of the IR trigger circuit that triggers on the tail end of the 
	  LED signal, hopefully this will have a more consistent latency since the automatic gain control 
	  is already adjusted (as the AGC adjustment seems to be the cause of the variable latency)
- [ ] Wire up and test the 32KHz buffered oscillator circuit. 
- [ ] Design the omni-directional transmitter (the object to be tracked). Current plan is to implement it as a hexagon
	  with an ultrasonic transmitter on each edge, and 360-degree-FoV IR emitter/demodulator pair on top.

## IR-triggered pitch-catch (`src/apps/ir_accuracy_test/`)
`sender/` + `receiver/` - wireless version of `receiver_readout`: the receiver's IR burst
(GPIO25, 38 kHz, 5 ms) triggers both sensors via each board's IR demodulator on INT1; GPIO2 is
high-impedance on both boards; GPIO26 held high powers the IR module. **Verified on hardware
(2026-09-28): end-to-end test passes.** See `src/apps/ir_accuracy_test/README.md`.
- [x] First on-hardware run (2026-09-28): receiver's IR burst triggers both sensors, and the
      receiver dumps the I/Q trace.
- [ ] Scope receiver GPIO25 (38 kHz, ~5 ms per Enter) and INT1 on both boards (clean low pulse,
      no contention from GPIO2).
- [x] Trigger edge (2026-09-28): LED idles low, demodulator and INT1 are both active-low, so the
      measurement starts on the falling edge at the start of the IR burst. The ~5 ms low pulse
      works; burst length doesn't affect trigger timing.
- [ ] Measure trigger skew between the two boards (INT1 falling edges on the scope) - this is the
      core accuracy number for this approach.
- [ ] Capture readouts at known distances and compare `range_mm` / waveforms against the hardwired
      `pitch_catch_mode_hardware_test` captures (`readouts/15ft`, `readouts/25ft`).
- [x] IR LED drive polarity (2026-09-28): active-high, idles low (off), as the firmware assumes.
- Receiver console menu (2026-10-02): `m` -> (1) IR timing tuner (optional pre-burst on/off +
  trigger-burst length, Space = test trigger), (2) raw I/Q readout, (3) distance (`RANGE` line).
  IR waveform moved from LEDC + busy-wait to RMT (exact to 1 us). **Builds clean, not yet run on
  hardware.**
  - [ ] Flash and walk through the menu: tuner prompts/echo, Backspace restart, Enter save, `m`
        from modes 2/3. Confirm the serial monitor's Enter doesn't fire twice.
  - [ ] Scope GPIO25 with a pre-burst (e.g. 600/600/5000 us): exact envelope, 38 kHz carrier,
        LED off between triggers.
  - [ ] Use the tuner to find the shortest reliable trigger burst and whether a pre-burst
        (demodulator AGC settling) tightens the trigger skew between the boards.

## Hardwired pitch-catch batch readout (`src/apps/pitch_catch_mode_hardware_test/receiver_readout/`)
Console now prompts for batch title / actual distance (mm) / reading count, then dumps N
`BEGIN`/`END` blocks (title + actual_mm + sensor summary + I/Q). `host/extract_measurements.py`
writes per-reading CSVs + `manifest.csv`. **Builds clean (2026-10-05), not yet run on hardware.**
- [ ] **Blocker (2026-10-05):** receiver's sensor reports op freq 1 Hz (PMUT clock count ~0); the
      POST now fails on this. Narrow it down: full power-cycle (unplug, not EN); run
      `echo_mode_hardware_test` on this board; swap boards (receiver_readout on the sender board);
      scope the sensor's 1.8 V rail during startup; recheck FFC seating / any recent rework.
- [ ] Flash and walk a batch: prompt echo/Backspace, single Enter starts the batch (no double fire
      from CR+LF), and N blocks come out for N readings.
- [ ] Check back-to-back readings don't hit `sender_not_ready`. If they do, measure how long the
      sender's INT2 (GPIO33) stays low and raise `SENDER_READY_TIMEOUT_MS`.
- [ ] Capture batches at several known distances (e.g. 250-3000 mm) and plot `range_mm` vs
      `actual_mm` from `manifest.csv` to get the hardwired baseline error/offset.

## Two-pass pitch-catch (`src/apps/two-pass_pitch_catch_test/receiver_readout/`)
Coarse f_op/4 pass picks a band, then a fine f_op/2 pass with a padded window. **Builds clean
(2026-10-08), not yet run on hardware.** See the app's README.
- [ ] Flash `sender` + `receiver_readout`. Check that the startup log shows meas 0 at ODR 5 and
      meas 1 at ODR 6, and that readings never come back `wrong_slot`.
- [ ] Capture batches in each band (e.g. 1 m, 2.5 m, 4 m). Check that the fine pulse lands at
      sample ≈ (coarse_mm - pad_mm) / Δ_fine. If the fine `range_mm` is about `pad_mm` short,
      SonicLib isn't compensating for the pad - add it in software.
- [ ] Check the mounting offsets (`TRANSMITTER_OFFSET` / `RECEIVER_OFFSET` in
      `sensor_calibration/include/sensor_offsets.h`, 23.25 mm each). They're added to the printed
      `range_mm`. Measure them on the units and see how much of the ranging offset they explain.
- [ ] Calibrate `TP_GATE_LEVEL` (and `TP_GATE_HALF_MM`) from the fine-pass I/Q. It is a placeholder.
- [ ] Watch for `sender_not_ready` on the fine trigger. If it shows up, raise `TP_PASS_GAP_MS`.
- [ ] Compare fine vs coarse `range_mm` spread at each distance, to see whether the extra
      resolution pays off.
- [ ] Once it's validated, port the flow to a live-distance receiver app. The copied `receiver/`
      was removed.

## Detection threshold calibration (`src/components/sensor_calibration/`)
8-segment `sc_rx_thresholds` fitted by `receiver_readout/host/calibrate_thresholds.py` from the
2026-10-07 captures (450 us / PW 4 TX burst, ODR f_op/4, 0.5-5 m). See `docs/threshold_calibration.md`.
Replay: 50/50 in all 14 batches, including 5 m at 30°, with 0 false detections.
**Used by the two-pass `receiver_readout`'s coarse pass (2026-10-09); not yet tested on hardware.**
- [ ] Finish the angle sweep: both boards turned up to 45° at each distance (especially 4-5 m at
      45°), then re-run the script (`--dry-run` first).
- [ ] Re-check the 5 m distance: its pulse arrives 6 samples (~93 mm) early. Every other batch is
      within ±2 samples.
- [ ] Integrate into `receiver_readout` (REQUIRES `sensor_calibration`, pass `&sc_rx_thresholds` to
      `icu_gpt_algo_configure()`), re-run batches and check the `target=1` rate in `manifest.csv`.
      Then do the same for `receiver/`. `ir_accuracy_test` still uses the old 80 us / ODR 4 settings
      (`ir_common.h`), so it needs those updated first.
- [ ] Pin down the threshold scale k (|I,Q| per threshold unit). The fits so far are 1.44-1.50
      (2026-10-07) and 1.45-1.70 (2026-10-05), so the detector isn't exactly |I,Q|/k. Capture a batch
      with a known-flat threshold near the signal level to measure it directly.
- [ ] Ranging offset. With the 450 us burst the firmware `range_mm` is 437 / 1430 / 2922 / 4022 at
      0.5 / 1.5 / 3 / 4 m. Detection fires on the pulse's 10-sample rising edge, so the error depends
      on signal strength. Find a correction, e.g. a fixed offset plus a dependence on amplitude.
- [ ] Update `extract_measurements.py` / `plot_readout.py` `--odr` defaults (still 4) to match `PC_ODR` (5).

## General performance tweaks
- [ ] Raise SPI clock if needed. Running at 1MHz right now, can go up to 13MHz
- [ ] Tune the `RF_*` `#define`s at the top of `rangefinder_loop.c` against real targets:
      thresholds (false targets vs missed targets), `RF_TX_PULSE_US` (far-target echo strength),
      `RF_RX_GAIN_REDUCE` / `RF_RINGDOWN_CANCEL_SAMPLES` (near-field / ringdown false targets).
- [ ] Optional, improves close-range accuracy: `ch_set_init_firmware(&dev, icu_init_init)` before
      `ch_group_start()` + `ch_meas_optimize()` after building the queue (auto-dampens ringdown;
      ~250 ms, run once). `icu_init` is already compiled in.

## Self-mapping relative coordinate system
The stationary beacons should be able to coordinate with each other and use distance from one another to establish their own local,
relative coordinate system in which to locate the mobile client. More research needed into the feasibility of this.

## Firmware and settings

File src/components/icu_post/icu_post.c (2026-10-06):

/*! \file icu_post.c
 *
 * \brief Implementation of the ICU-20201 power-on self-test. See icu_post.h.
 */

#include "icu_post.h"

#include <inttypes.h>
#include <stdio.h>
#include <string.h>

#include "esp_log.h"

#include <invn/soniclib/soniclib.h>
#include <invn/soniclib/details/ch_driver.h>       /* chdrv_prog_ping(), chdrv_dbg_reg_read() */
#include <invn/soniclib/details/ch_asic_shasta.h>  /* SYS_CTRL_*, SHASTA_DBG_REG_CPU_ID_HI */
#include <invn/soniclib/details/ch_common.h>       /* PMUT_FREQUENCY_ERROR_CODE */

/* The ICU-20201 is a Shasta-generation SPI part. SonicLib selects SPI vs I2C at compile time;
 * without INCLUDE_SHASTA_SUPPORT it falls back to the CHx01 / I2C path and this POST's SPI
 * checks would be meaningless. Catch a misconfigured build here. */
#if !defined(INCLUDE_SHASTA_SUPPORT) || defined(INCLUDE_WHITNEY_SUPPORT)
#error "Build SonicLib with INCLUDE_SHASTA_SUPPORT and without INCLUDE_WHITNEY_SUPPORT for the ICU-20201"
#endif

static const char *TAG = "POST";

/* ICU-20201 acoustic operating frequency f_op is 85 kHz nominal, 70-95 kHz over process/temp
 * (DS-000478: "nominally 85kHz PMUT"; Operating Frequency 70/85/95 kHz min/typ/max). A reading
 * outside this window (with a little margin) fails the POST: every sample-count and range
 * conversion SonicLib does scales with f_op, so a bad value silently breaks the measurement config
 * (e.g. f_op = 1 Hz -> 1 active sample). */
#define POST_FREQ_PLAUSIBLE_LO_HZ 65000u
#define POST_FREQ_PLAUSIBLE_HI_HZ 100000u

void post_config_default(post_config_t *cfg) {
	if (cfg == NULL) {
		return;
	}
	cfg->run_group_start      = true;
	cfg->stop_on_fail         = true;
	cfg->expected_part_number = ICU20201_PART_NUMBER;
}

static void stage_set(post_stage_result_t *s, bool pass, int code, const char *detail) {
	s->run  = true;
	s->pass = pass;
	s->code = code;
	strncpy(s->detail, (detail != NULL) ? detail : "", sizeof(s->detail) - 1);
	s->detail[sizeof(s->detail) - 1] = '\0';
}

/* ---- Stage 1: SPI link -------------------------------------------------------------------- */
/* chdrv_prog_ping() exercises CS + SCLK + MOSI + MISO through the BSP's chbsp_spi_* callbacks:
 * it writes the sensor's SYS_CTRL register to hold and release reset, then reads the CPU_ID_HI
 * debug register and checks it equals SHASTA_CPU_ID_HI_VALUE. Returns 1 when the sensor answers
 * with the expected ID. This is the core "can the ESP32 talk to the module over SPI" check. */

/* Raw CPU_ID_HI read (mirrors the core of chdrv_prog_ping) so the log shows exactly what came
 * back over MISO - that value pins down the failure mode when the ping fails. */
static uint16_t read_cpu_id_hi(ch_dev_t *dev, uint8_t *err_out) {
	uint8_t  err = 0;
	uint16_t id  = 0;
	err |= chdrv_sys_ctrl_write(dev, SYS_CTRL_DEBUG);                     /* assert reset, debug mode */
	err |= chdrv_sys_ctrl_write(dev, SYS_CTRL_DEBUG | SYS_CTRL_RESET_N);  /* release reset */
	err |= chdrv_dbg_reg_read(dev, SHASTA_DBG_REG_CPU_ID_HI, &id);
	if (err_out != NULL) {
		*err_out = err;
	}
	return id;
}

static bool stage_spi_link(ch_dev_t *dev, post_stage_result_t *s) {
	uint8_t  rd_err = 0;
	uint16_t cpu_id = read_cpu_id_hi(dev, &rd_err);
	ESP_LOGI(TAG, "        CPU_ID_HI raw read = 0x%04X (want 0x%04X)%s", cpu_id, SHASTA_CPU_ID_HI_VALUE,
	         rd_err ? "  [BSP SPI transfer error]" : "");

	if (chdrv_prog_ping(dev)) {
		stage_set(s, true, 0, "prog_ping OK - sensor returned the expected CPU ID");
		ESP_LOGI(TAG, "[1/3] SPI link ......... PASS  (CPU ID 0x%04X matched)", SHASTA_CPU_ID_HI_VALUE);
		return true;
	}

	const char *hint;
	if (rd_err) {
		hint = "BSP SPI transfer returned error - SPI bus / chbsp_spi_* problem";
	} else if (cpu_id == 0x0000) {
		hint = "MISO reads all-0 - sensor unpowered (1.8V VDD?), no SCLK, or MISO not wired";
	} else if (cpu_id == 0xFFFF) {
		hint = "MISO reads all-1 - MISO floating / not driven; check MISO, CS (GPIO5), FFC seat";
	} else {
		hint = "wrong CPU ID - SPI mode (want mode 3), bit order, clock too fast, or level shifter";
	}
	stage_set(s, false, 1, hint);
	ESP_LOGE(TAG, "[1/3] SPI link ......... FAIL  (%s)", hint);
	return false;
}

/* ---- Stage 2: program + start ----------------------------------------------------------- */
static bool stage_group_start(ch_group_t *grp, ch_dev_t *dev, post_stage_result_t *s) {
	uint8_t rc = ch_group_start(grp);
	if (rc != 0) {
		char d[72];
		snprintf(d, sizeof(d), "ch_group_start() returned %u", rc);
		stage_set(s, false, (int)rc, d);
		ESP_LOGE(TAG, "[2/3] Program + start .. FAIL  (ch_group_start rc=%u)", rc);
		return false;
	}
	if (!ch_sensor_is_connected(dev)) {
		stage_set(s, false, 2, "ch_group_start() ok but sensor not marked connected");
		ESP_LOGE(TAG, "[2/3] Program + start .. FAIL  (sensor not connected after start)");
		return false;
	}
	stage_set(s, true, 0, "firmware loaded, frequency locked, RTC calibrated");
	ESP_LOGI(TAG, "[2/3] Program + start .. PASS");
	return true;
}
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

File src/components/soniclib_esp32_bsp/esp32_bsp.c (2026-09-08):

/*! \file esp32_bsp.c
 *
 * \brief ESP32 (esp-idf) board support package for SonicLib, for a single ICU-20201 sensor
 * connected over SPI. See chirp_bsp.h for the function contracts and esp32_bsp_internal.h for
 * pin assignments.
 *
 * All functions here depend on chbsp_esp32_init() (chbsp_esp32_init.c) having already been
 * called by the application.
 */

#include <invn/soniclib/chirp_bsp.h>
#include "esp32_bsp_internal.h"

#include <string.h>
#include <stdio.h>

#include "esp_rom_sys.h"
#include "esp_timer.h"

/* ===================== INT1 (hardware trigger, CHIRP_SENSOR_TRIG_PIN) ===================== */

void chbsp_group_set_int1_dir_out(ch_group_t *grp_ptr) {
	(void)grp_ptr;
	gpio_set_direction(BSP_PIN_INT1, GPIO_MODE_OUTPUT);
}

void chbsp_set_int1_dir_out(ch_dev_t *dev_ptr) {
	(void)dev_ptr;
	gpio_set_direction(BSP_PIN_INT1, GPIO_MODE_OUTPUT);
}

void chbsp_group_set_int1_dir_in(ch_group_t *grp_ptr) {
	(void)grp_ptr;
	gpio_set_direction(BSP_PIN_INT1, GPIO_MODE_INPUT);
}

void chbsp_set_int1_dir_in(ch_dev_t *dev_ptr) {
	(void)dev_ptr;
	gpio_set_direction(BSP_PIN_INT1, GPIO_MODE_INPUT);
}

void chbsp_group_int1_clear(ch_group_t *grp_ptr) {
	(void)grp_ptr;
	gpio_set_level(BSP_PIN_INT1, 0); /* active low */
}

void chbsp_int1_clear(ch_dev_t *dev_ptr) {
	(void)dev_ptr;
	gpio_set_level(BSP_PIN_INT1, 0);
}

void chbsp_group_int1_set(ch_group_t *grp_ptr) {
	(void)grp_ptr;
	gpio_set_level(BSP_PIN_INT1, 1); /* inactive high */
}

void chbsp_int1_set(ch_dev_t *dev_ptr) {
	(void)dev_ptr;
	gpio_set_level(BSP_PIN_INT1, 1);
}

/* INT1 is the trigger pin on this board (CHIRP_SENSOR_TRIG_PIN=1); SonicLib never arms an
 * interrupt on it, so chbsp_int1_interrupt_enable()/disable() are left to the chbsp_dummy.c
 * no-op stubs. The interrupt-enable control lives in the INT2 block below. */

/* ===================== INT2 (data-ready interrupt, CHIRP_SENSOR_INT_PIN) ===================== */

void chbsp_group_set_int2_dir_out(ch_group_t *grp_ptr) {
	(void)grp_ptr;
	gpio_set_direction(BSP_PIN_INT2, GPIO_MODE_OUTPUT);
}

void chbsp_set_int2_dir_out(ch_dev_t *dev_ptr) {
	(void)dev_ptr;
	gpio_set_direction(BSP_PIN_INT2, GPIO_MODE_OUTPUT);
}

void chbsp_group_set_int2_dir_in(ch_group_t *grp_ptr) {
	(void)grp_ptr;
	gpio_set_direction(BSP_PIN_INT2, GPIO_MODE_INPUT);
}

void chbsp_set_int2_dir_in(ch_dev_t *dev_ptr) {
	(void)dev_ptr;
	gpio_set_direction(BSP_PIN_INT2, GPIO_MODE_INPUT);
}

void chbsp_group_int2_clear(ch_group_t *grp_ptr) {
	(void)grp_ptr;
	gpio_set_level(BSP_PIN_INT2, 0); /* active low */
}

void chbsp_int2_clear(ch_dev_t *dev_ptr) {
	(void)dev_ptr;
	gpio_set_level(BSP_PIN_INT2, 0);
}

void chbsp_group_int2_set(ch_group_t *grp_ptr) {
	(void)grp_ptr;
	gpio_set_level(BSP_PIN_INT2, 1); /* inactive high */
}

void chbsp_int2_set(ch_dev_t *dev_ptr) {
	(void)dev_ptr;
	gpio_set_level(BSP_PIN_INT2, 1);
}

void chbsp_group_int2_interrupt_enable(ch_group_t *grp_ptr) {
	(void)grp_ptr;
	gpio_intr_enable(BSP_PIN_INT2);
}

void chbsp_int2_interrupt_enable(ch_dev_t *dev_ptr) {
	(void)dev_ptr;
	gpio_intr_enable(BSP_PIN_INT2);
}

void chbsp_group_int2_interrupt_disable(ch_group_t *grp_ptr) {
	(void)grp_ptr;
	gpio_intr_disable(BSP_PIN_INT2);
}

void chbsp_int2_interrupt_disable(ch_dev_t *dev_ptr) {
	(void)dev_ptr;
	gpio_intr_disable(BSP_PIN_INT2);
}

/* ===================== SPI ===================== */

void chbsp_spi_cs_on(ch_dev_t *dev_ptr) {
	(void)dev_ptr;
	gpio_set_level(BSP_PIN_SPI_CS, 0);
}

void chbsp_spi_cs_off(ch_dev_t *dev_ptr) {
	(void)dev_ptr;
	gpio_set_level(BSP_PIN_SPI_CS, 1);
}

int chbsp_spi_write(ch_dev_t *dev_ptr, const uint8_t *data, uint16_t num_bytes) {
	(void)dev_ptr;
	if (num_bytes == 0) return 0;
	if (num_bytes > BSP_SPI_SCRATCH_BYTES) return 1;

	/* Copy through a DMA-capable scratch buffer - callers within soniclib do not guarantee their
	 * buffers are DMA-capable, and this bus uses DMA (required for transfers over 64 bytes). */
	memcpy(bsp_spi_scratch, data, num_bytes);

	spi_transaction_t trans = {
			.length    = (size_t)num_bytes * 8,
			.tx_buffer = bsp_spi_scratch,
	};
	esp_err_t err = spi_device_transmit(bsp_spi_handle, &trans);
	return (err == ESP_OK) ? 0 : 1;
}

int chbsp_spi_read(ch_dev_t *dev_ptr, uint8_t *data, uint16_t num_bytes) {
	(void)dev_ptr;
	if (num_bytes == 0) return 0;
	if (num_bytes > BSP_SPI_SCRATCH_BYTES) return 1;

	spi_transaction_t trans = {
			.length    = (size_t)num_bytes * 8,
			.rx_buffer = bsp_spi_scratch,
	};
	esp_err_t err = spi_device_transmit(bsp_spi_handle, &trans);
	if (err != ESP_OK) return 1;

	memcpy(data, bsp_spi_scratch, num_bytes);
	return 0;
}

/* ===================== Delay / timestamp ===================== */

void chbsp_delay_us(uint32_t us) {
	esp_rom_delay_us(us);
}

void chbsp_pulse_len_hint_us(uint32_t us) {
	chbsp_delay_us(us);
}

/* Busy-wait rather than vTaskDelay(): CONFIG_FREERTOS_HZ=100 (10ms tick) is too coarse for the
 * RTC calibration pulse timed by this function, whose accuracy directly affects range accuracy
 * (see chirp_bsp.h). Only used for short one-time delays during ch_group_start(), not in the
 * measurement hot path. */
void chbsp_delay_ms(uint32_t ms) {
	esp_rom_delay_us(ms * 1000);
}

uint32_t chbsp_timestamp_ms(void) {
	return (uint32_t)(esp_timer_get_time() / 1000);
}

/* ===================== Event wait/notify ===================== */

void chbsp_event_wait_setup(uint32_t event_mask) {
	xEventGroupClearBits(bsp_event_group, event_mask);
}

uint8_t chbsp_event_wait(uint16_t time_out_ms, uint32_t event_mask) {
	EventBits_t bits = xEventGroupWaitBits(bsp_event_group, event_mask, pdFALSE, pdTRUE,
	                                       pdMS_TO_TICKS(time_out_ms));
	return ((bits & event_mask) == event_mask) ? 0 : 1;
}

/* Called from ch_interrupt() to wake chbsp_event_wait(). ch_interrupt() runs in bsp_int_task
 * (task context), but stay ISR-safe in case a future path calls it from an ISR. */
void chbsp_event_notify(uint32_t event_mask) {
	if (xPortInIsrContext()) {
		BaseType_t higher_priority_task_woken = pdFALSE;
		xEventGroupSetBitsFromISR(bsp_event_group, event_mask, &higher_priority_task_woken);
		portYIELD_FROM_ISR(higher_priority_task_woken);
	} else {
		xEventGroupSetBits(bsp_event_group, event_mask);
	}
}

/* ===================== Debug output ===================== */

void chbsp_print_str(const char *str) {
	printf("%s", str);
}

/* ===================== INT2 data-ready: ISR + deferring task ===================== */
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

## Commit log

2026-06-25 Added Kicad schematics for CH201 rangefinder test circuitry
2026-06-25 moved picture of test rig schematic to pics/
2026-07-05 Revised test rig schematic to use newer ICU-20201 ultrasonic chips
2026-07-08 Claude wrote the ESP32 board support package for soniclib to drive the ICU-20201 ultrasonic sensors
2026-07-24 Designed master/slave beacon PCB
2026-09-06 Got hardware power-on self-test working
2026-09-06 Applied gitignore to already-committed files
    [Rangefinder_test_schematic_v3-B_Cu.gbr, Rangefinder_test_schematic_v3-B_Mask.gbr, Rangefinder_test_schematic_v3-B_Paste.gbr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]
2026-09-11 Cleaned up documentation for power-on self-test component
2026-09-11 Added pitch-catch test firmware- not hardware tested
2026-09-24 Experimented with FTSP for time sync + automated sensor tuning
2026-09-24 Added 3d print files for stand
    [BoardMountV1.stl, FeetV1.stl]
2026-09-25 Added firmware for raw I/Q readout in pitch-catch over wire, plus visualizer
    [15ft_1.csv, 15ft_10.csv, 15ft_11.csv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]
2026-09-28 Added infrared triggering firmware for wireless measurements
2026-10-06 Modified pitch-catch test code to make measurement collection easier
    [15ft_1.csv, 15ft_10.csv, 15ft_11.csv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]
2026-10-08 Adjusted sensor calibration (ODR, pulse width, burst length), re-measured sample data for tuning
2026-10-08 Refactored sensor config to a common src/component for future apps to pull in
2026-10-09 Added offset correction to sensor readings. Untested
    [readout_loop.c]
2026-10-09 Two-pass receiver code no longer prints raw I/Q for coarse pass
    [readout_loop.c]
2026-10-09 2-pass receiver code now pulls in most current threshold values
2026-10-15 Switched to ASK instead of OOK for CC1101 synchronous triggering- works well
